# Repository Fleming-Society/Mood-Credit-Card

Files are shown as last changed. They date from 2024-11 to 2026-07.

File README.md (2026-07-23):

# Mood Credit Card

An educational electronics project from Fleming Society's 2024 Project X
programme. Participants use an ESP32-C3, a MAX30102 optical pulse sensor and
five LEDs to learn embedded programming, signal processing and PCB design.

> [!IMPORTANT]
> This is an educational demonstration, not a medical device. Heart-rate
> readings must not be used for diagnosis, monitoring or treatment.

## At a glance

| Item | Details |
| --- | --- |
| Programme | Project X 2024 |
| Topics | Arduino, ESP32-C3, sensors, I2C, signal processing and PCB design |
| Main hardware | ESP32-C3 SuperMini, MAX30102 module, five LEDs and five 220 Ω resistors |
| Firmware | Arduino sketch using the DevXplained MAX3010x Sensor Library |
| Design tools | KiCad, SolidWorks and a retained legacy DesignSpark PCB file |
| Current status | Recovered 2024 teaching pack; technical revalidation is required before another delivery |

## Project preview

| Project X workshop | Mood Credit Card model |
| --- | --- |
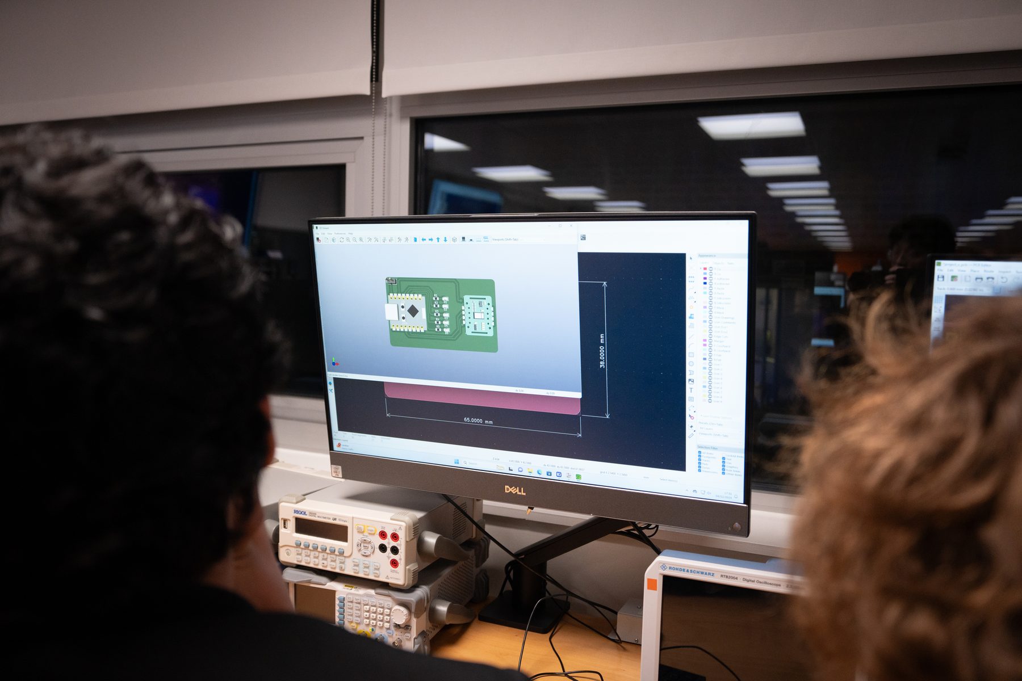
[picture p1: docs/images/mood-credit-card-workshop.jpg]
Project X participants viewing the Mood Credit Card design in KiCad
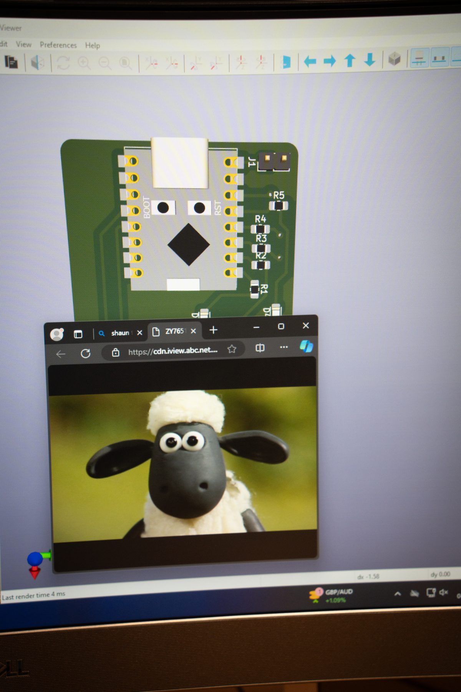
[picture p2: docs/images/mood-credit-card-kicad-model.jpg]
Mood Credit Card PCB model displayed in KiCad
|  |  |

### Circuit schematic

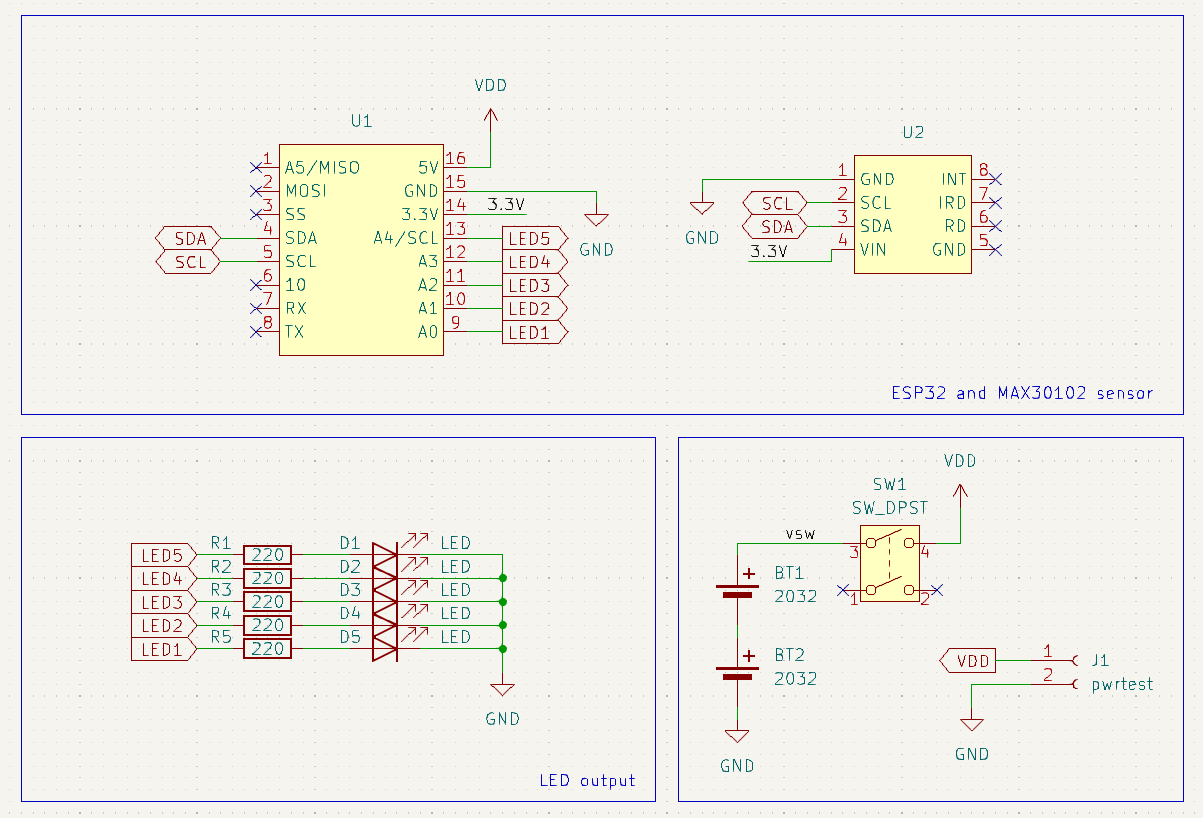
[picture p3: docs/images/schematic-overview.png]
Mood Credit Card circuit schematic


## Start here

- **Learners:** begin with the [session materials](docs/learner/README.md),
  then open the [student firmware](firmware/student/mood_credit_card/).
- **Instructors:** read the [instructor notes](docs/instructor/README.md) and
  recovered session plans before preparing a session.
- **Hardware contributors:** read the [hardware guide](hardware/README.md)
  before editing or manufacturing the PCB.

PDF handouts survive for sessions 1, 3 and 5. Session 2 now has its recovered
agenda and I2C example code. Session 5 also has editable helper slides and an
instructor plan. No separate Session 4 handout was found in the source archive.

## Repository structure

```text
.
|-- docs/             # Learner and instructor material
|-- firmware/         # Maintained code, examples and historical snapshots
|-- hardware/         # Current CAD, enclosure source and historical revisions
|-- private/          # Local-only records and raw source archives, ignored by Git
|-- third_party/      # Imported material and preserved licence texts
|-- CONTRIBUTING.md
|-- LICENSE
`-- NOTICE.md
```

This layout is intended to be reused across Fleming Society projects:
documentation in `docs/`, runnable code in `firmware/`, editable engineering
source in `hardware/`, and personal or operational records outside the public
Git history.

## Recovered 2024 material

| Material | Location | Notes |
| --- | --- | --- |
| Learner handouts, PCB guide and I2C slides | [`docs/learner/2024/`](docs/learner/2024/) | Original 2024 files; review before reuse |
| Instructor agendas and plans | [`docs/instructor/2024/`](docs/instructor/2024/) | Session 2 and Session 5 material recovered |
| I2C Arduino examples | [`firmware/examples/session-02/`](firmware/examples/session-02/) | Arduino Uno slave and ESP8266 master |
| Learner KiCad project | [`hardware/kicad/learner/`](hardware/kicad/learner/) | Complete source set recovered; not yet revalidated |
| Enclosure CAD | [`hardware/enclosure/`](hardware/enclosure/) | SolidWorks source and STL exports |
| Historical PCB revisions | [`hardware/archive/2024/`](hardware/archive/2024/) | Seven labelled development stages; caches and automatic backups omitted |

## Software setup

1. Install the Arduino IDE and ESP32 board support.
2. Install the
   [MAX3010x Sensor Library](https://github.com/devxplained/MAX3010x-Sensor-Library)
   by DevXplained.
3. Open
   `firmware/student/mood_credit_card/mood_credit_card.ino`.
4. Select the correct ESP32-C3 board and port.
5. Compile before connecting the workshop PCB.

The exact Arduino ESP32 core and library versions used in 2024 were not
recorded. Pin these versions after the firmware is revalidated.

## Validation status

| Area | Status | Required action |
| --- | --- | --- |
| Learner materials | Recovered from 2024 | Review wording, links and software screenshots |
| Student firmware | Not recently compiled | Confirm board target, library version and sampling behaviour |
| Learner KiCad project | Source set recovered | Open in the intended KiCad version; run ERC and DRC |
| Exemplar KiCad design | Source preserved | Compare with an approved fabricated board |
| Enclosure CAD | Source and STL variants recovered | Confirm assembly references, fit and preferred revision |
| Component 3D models | Withheld pending licence review | Replace with redistributable models and document provenance |
| Gerbers | Current and historical sets preserved | Identify the approved set before manufacturing |
| Bill of materials | 2024 workbook preserved | Review prices, part numbers and substitutions |
| Risk assessment | Missing | Add the current session risk assessment and supervision notes |

## Safety

- Power the board only from the documented low-voltage USB supply.
- Inspect assembled boards for shorts before connecting them to a computer.
- Do not look directly into the pulse sensor LEDs at close range.
- Follow the venue's soldering, ESD and tool-safety procedures.
- Do not collect or publish participants' health readings or attendance data.

## Contributing

See [CONTRIBUTING.md](CONTRIBUTING.md) for file-placement, privacy and review
rules.

## Licensing

Except where a file or notice says otherwise, the original teaching material,
firmware and hardware designs are available under the [MIT License](LICENSE).

Third-party material retains its original copyright and licence. See
[NOTICE.md](NOTICE.md) and the licence texts under [`third_party/`](third_party/).

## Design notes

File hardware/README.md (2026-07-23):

# Hardware

## Editable PCB sources

[`kicad/`](kicad/) contains the completed KiCad exemplar, custom symbols and
custom footprints. [`kicad/learner/`](kicad/learner/) contains the recovered
2024 learner starter project with its board, schematic and project file.

The board files use `${KIPRJMOD}`-relative references. The supplied component
STEP models are withheld from the public tree until their redistribution
rights are confirmed; see
[`kicad/3d_models/README.md`](kicad/3d_models/README.md).

## Enclosure CAD

[`enclosure/`](enclosure/) contains recovered SolidWorks source and STL
exports for the enclosure. Several back variants survive, and no preferred
release has been confirmed.

## Historical revisions

[`archive/2024/`](archive/2024/) contains seven labelled PCB development
stages recovered from the source ZIP. They are retained for traceability, not
as alternatives to the current exemplar or learner project.

## Manufacturing outputs

[`manufacturing/gerbers/`](manufacturing/gerbers/) contains the previously
selected historical Gerber and drill files. Additional revision-specific sets
are retained with their matching source under `archive/2024/`.

Do not send any set to manufacture until the schematic and PCB pass ERC, DRC
and a human design review against an approved fabricated board.

## Bill of materials

[`bom/2024/bom.xlsx`](bom/2024/bom.xlsx) is the supplied 2024 bill of
materials. Prices, stock, supplier links and part substitutions have not yet
been reviewed for a future delivery.

## Legacy source

[`legacy/`](legacy/) contains an older binary `.dip` design file. Retain it for
traceability until its application, version and relationship to the KiCad
design are documented.

## Repository hygiene

KiCad caches, user preferences and automatic backups are not public project
source. The untouched `project_x.zip` source drop is retained under ignored
`private/source-archive/` as a lossless fallback. Unverified third-party
models and libraries are held separately under `private/licensing-review/`
and are not covered by the project licence.

Before the next release:

- convert the BOM into a supplier-neutral master list with optional supplier
  columns;
- confirm board dimensions and connector pinout;
- choose and validate an enclosure revision;
- add assembly instructions and known design limitations; and
- record the KiCad version used for final ERC and DRC.

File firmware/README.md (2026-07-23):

# Firmware

The current learner starter sketch is at
[`student/mood_credit_card/`](student/mood_credit_card/).

Recovered I2C examples from Session 2 are under
[`examples/session-02/`](examples/session-02/). Historical prototype ZIP
snapshots are retained under
[`archive/2024/prototypes/`](archive/2024/prototypes/) for comparison, not as
the primary learner code.

Before the next workshop:

1. Confirm the exact ESP32-C3 board target.
2. Pin the Arduino ESP32 core and DevXplained MAX3010x library versions.
3. Compile from a fresh environment.
4. Verify that `readBPM()` is called frequently enough to sample a heartbeat;
   it should not run only once per second.
5. Resolve or document the current 3200 SPS sensor setting versus the 400 Hz
   filter sampling-frequency constant.
6. Test behaviour with no finger, poor contact and sensor disconnection.

Keep learner starter code separate from any worked solution. If solutions
must remain restricted, store them outside this public repository.

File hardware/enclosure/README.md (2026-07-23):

# Enclosure CAD

The recovered 2024 SolidWorks and STL files are grouped by development stage:

- [`2024/v3/`](2024/v3/) contains the v3 assembly, enclosure and back variants.
- [`2024/earlier-revisions/`](2024/earlier-revisions/) contains earlier
  enclosure and assembly files.

The SolidWorks assemblies may refer to component models that are not publicly
distributed because their licences are unconfirmed. Open the part files first
if an assembly reports missing references.

No preferred enclosure revision has been identified. Check dimensions,
connector access, print tolerances, board fit and sensor access before using
an STL for fabrication.

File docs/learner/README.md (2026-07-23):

# Learner materials

## Project X 2024

The recovered learner materials are in [`2024/`](2024/):

1. [Session 1 handout](2024/session-01.pdf)
2. [Session 3 handout](2024/session-03.pdf)
3. [Session 5 handout](2024/session-05.pdf)
4. [Session 5 I2C helper slides](2024/session-05-i2c-helper-slides.pptx)
5. [PCB design instructions](2024/pcb-instructions.docx)

Session 2 used an instructor agenda and I2C practical code rather than a
learner-facing handout in the recovered archive. See the
[Session 2 examples](../../firmware/examples/session-02/). No separate Session
4 learner handout was found.

Editable source files for the three PDF handouts have not yet been located.

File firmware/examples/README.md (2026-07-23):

# Firmware examples

Small, self-contained examples used by historical teaching sessions belong
here. Each Arduino sketch must stay in a directory that matches its `.ino`
filename.

The recovered Session 2 examples demonstrate I2C communication between an
ESP8266 master and an Arduino Uno slave. They have not been compiled recently.

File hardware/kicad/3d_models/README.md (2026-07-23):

# 3D model placeholders

The KiCad boards reference models for the ESP32-C3 SuperMini and MAX30102
module, but the supplied STEP files are not distributed here because their
copyright and redistribution terms have not been confirmed.

Local copies are held in the ignored `private/licensing-review/3d-models/`
directory while their provenance is investigated. Replace them with models
whose licences permit redistribution, then record their authors, sources and
licences in the root [`NOTICE.md`](../../../NOTICE.md).

The PCB and schematic sources remain usable without the 3D models. KiCad's 3D
viewer will show the corresponding components without models until suitable
replacements are added.

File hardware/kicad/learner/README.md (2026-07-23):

# Learner KiCad starter

This is the recovered 2024 learner PCB template. It contains the ESP32-C3 and
MAX30102 circuit, with the two main footprints locked, but no routed tracks or
learner-designed LED circuit.

The source set now includes:

- `project_x_pcb.kicad_pro`
- `project_x_pcb.kicad_sch`
- `project_x_pcb.kicad_pcb`
- local library tables that point to the shared custom libraries one directory
  above

The files were recovered from the full `project_x.zip` source archive. They
have not yet been opened together in the intended KiCad version or checked
with ERC and DRC, so treat them as recovered historical source rather than a
validated release.

The board's 3D model references point to `../3d_models/`, but the component
models are deliberately absent pending licence confirmation. See
[`../3d_models/README.md`](../3d_models/README.md).

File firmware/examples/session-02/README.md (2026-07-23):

# Session 2 I2C examples

| Sketch | Target | Purpose |
| --- | --- | --- |
| [`arduino_slave/arduino_slave.ino`](arduino_slave/arduino_slave.ino) | Arduino Uno | Receives text at I2C address 9 and prints it to Serial |
| [`esp8266_master/esp8266_master.ino`](esp8266_master/esp8266_master.ino) | ESP8266 | Reads Serial input and sends it to I2C address 9 |

The recovered agenda describes removing selected expressions before the
exercise so learners can fill them in. The copies here preserve the complete
reference implementations. Confirm voltage compatibility, board pins and the
installed board packages before wiring the two devices together.

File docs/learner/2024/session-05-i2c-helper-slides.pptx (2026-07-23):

## I2C exercise: Arduino_slave and Arduino_master Helper slides

## Arduino_slave: What is the task?

- This Arduino code allows Arduino to receive messages over I²C (a communication protocol) and print the received messages to the Serial Monitor.
- Specifically, the Arduino acts as a slave device with an address of 9. When data is sent to this address, the code reads the data, stores it in a buffer (a temporary storage space), and displays it on the Serial Monitor.
- Write you code following the steps and ask volunteers for help!

## Step 1: Include the Required Library

- Library: You'll need the Wire library to enable I²C communication.
- Write an #include statement at the very top of the code to include this library.
Why?
- The Wire library allows your Arduino to send and receive data over the I²C bus.

## Step 2: Define the Buffer Size

- Buffer Size: Create a constant called BUFFER_SIZE and set it to 32.
- This defines how much data (in characters) your Arduino can store when receiving messages.
Why?
- This buffer will store incoming data, and 32 is a maximum reasonable size to work with, considering Arduino's memory limitations.

## Step 3: Declare the Buffer and Index

- Buffer: Create a character array called receivedText with a size of BUFFER_SIZE.
- This will store the received message.
- Index: Create an integer variable called textIndex and set it to 0.
- This will track where the next character should be stored in the buffer.
Why?
- The buffer stores the incoming data as characters. The index keeps track of where to place each character.

## Step 4: Set Up the Arduino (Setup Function)

- Write a setup function. This function runs once when the Arduino starts. (it should be there when you create a new file)
- Start Serial Communication:
- Inside the setup, initialize the Serial Monitor with a baud rate of 9600 using Serial.begin();.
- This allows you to see messages printed to your computer.

## Step 4: Set Up the Arduino (Setup Function)

- Start I²C Communication:
- Initialize the Arduino as an I²C slave device with the address 9 using Wire.begin().
- Register the Receive Event:
- Attach a function called receiveEvent using Wire.onReceive().
- This function will automatically run whenever the Arduino receives data.
Why?
- The setup function prepares the Arduino for serial communication and I²C communication.

## Step 5: Write the Receive Event Function

- Create a function called receiveEvent that:
- Type: void (it doesn't return any value).
- Input: An integer called bytes, which represents the number of bytes available to read.
- Reset the Index:
- At the beginning of the function, set textIndex to 0 to clear the buffer for new data.

## Step 5: Write the Receive Event Function

Read Incoming Data:
- Use a loop to read each byte from the I²C buffer:
- As long as there are bytes available (Wire.available()), read one byte at a time and store it in a variable c of type char.
- Store Data in the Buffer:
- If textIndex is less than BUFFER_SIZE - 1:
- Store c in the receivedText array at the position textIndex.
- Increment textIndex by 1.
Loop to read each byte from the I²C buffer end here.

## Step 5: Write the Receive Event Function

- Add a Null-Terminator:
- After reading all the bytes, add a \0 (null-terminator) to receivedText to mark the end of the string.
Why?
- This function processes the data received over I²C and stores it as a proper string. The null-terminator is crucial to indicate the end of the text.

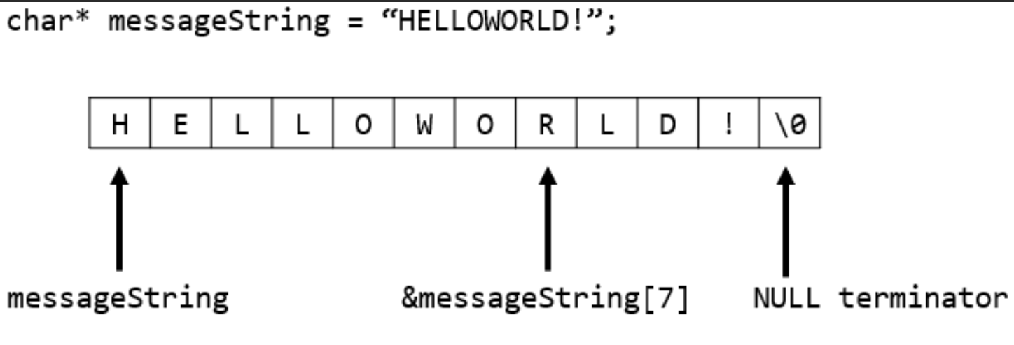
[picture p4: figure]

## Step 6: Write the Loop Function

- Create a loop function. This function runs repeatedly.(it should be there when you create a new file)
- Check for New Data:
- If textIndex is greater than 0 (meaning data has been received), print the message.
- Print the Message:
- Use Serial.println to display the message in receivedText on the Serial Monitor.

## Step 6: Write the Loop Function

- Reset the Index:
- After printing, reset textIndex to 0 to prepare for the next message.
Why?
- The loop function continuously checks if there's a new message to print. Resetting textIndex allows the buffer to be reused.

## Variable Summary for Arduino_slave

Variable | Type | Purpose
BUFFER_SIZE | #define | Maximum size of the receivedText buffer (32).
receivedText | char[] | Buffer to store the incoming message.
textIndex | int | Tracks the current position in the buffer.
c | char | Stores each character read from the I²C buffer.
bytes | int | Number of bytes available to read in the receiveEvent function.

## Arduino_master: What is the task?

- This code allows an Arduino to act as an I²C master. The master device reads input from the Serial Monitor, stores it as a string, and then sends this string to an I²C slave device (like the Arduino Uno) with the address 9.
- After sending the message, it prints a confirmation to the Serial Monitor.

## Step 1: Include the Required Library

- Library: You'll need the Wire library to enable I²C communication.
- Write an #include statement at the very top of the code to include this library.
Why?
- The Wire library allows your Arduino to send and receive data over the I²C bus.

## Step 2: Define the Buffer Size and Input Buffer

- Buffer Size: Define a constant BUFFER_SIZE with a value of 32.
- Input Buffer: Declare a character array called inputText with a size of BUFFER_SIZE.
- This array will store the text that the user inputs from the Serial Monitor.
- Why?
- The buffer allows you to temporarily store the input message before sending it over I²C.

## Step 3: Set Up the Arduino (Setup Function)

- Write a setup function. This function runs once when the Arduino starts. (it should be there when you create a new file)
- Start Serial Communication:
- Initialize the Serial Monitor with a baud rate of 9600 using Serial.begin();.
- This allows you to send and receive text via your computer.

## Step 3: Set Up the Arduino (Setup Function)

- Initialize I²C Communication:
- Call Wire.begin(); to set up the Arduino as an I²C master.
- Print a Welcome Message:
- Print a message prompting the user to type a message and press Enter.
Why?
- The setup function prepares the Arduino for communication and informs the user how to interact with the device.

## Step 4: Write the Loop Function

- Create a loop function. This function runs repeatedly. (it should be there when you create a new file)
- Check for User Input:
- Use Serial.available() to check if there is any input available in the Serial Monitor. They are available if Serial.available() is greater than 0.

## Step 4: Write the Loop Function

Read Input:
- Use the Serial.readBytesUntil() function to achieve this. This function reads characters until it encounters a newline or reaches the maximum number of characters allowed.
- Read characters from the Serial Monitor until a newline character (\n) is received, meaning the user pressed Enter or the buffer is full (up to BUFFER_SIZE - 1).
- Store the characters in the inputText buffer.
- Save the length of the input in a variable len.
- len is declared as a size_t because Serial.readBytesUntil() returns the number of characters read, which is a size value.

## Step 4: Write the Loop Function

- Add a Null-Terminator:
- Add a \0 (null-terminator) to the end of inputText to mark it as a valid string.
- Send Data via I²C:
- Use Wire.beginTransmission() to start communication with the slave device at address 9.
- Send the string stored in inputText using Wire.write();.
- End the I²C transmission with Wire.endTransmission();.

## Step 4: Write the Loop Function

- Print Confirmation:
- Print a message to the Serial Monitor showing the text that was sent. Use Serial.println();
- Prompt the user to type another message. Serial.println();
Why?
- This function continuously checks for new input and sends it to the I²C slave. Adding a null-terminator ensures the string is properly formatted.
- The if loop ends here.
- The loop function ends here.

## Variable Summary for Arduino_master

Variable | Type | Purpose
BUFFER_SIZE | #define | Maximum size of the inputText buffer (32).
inputText | char[] | Buffer to store the user’s input message.
len | size_t | Length of the input string read from the Serial Monitor.

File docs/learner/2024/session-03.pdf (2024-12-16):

Project X Session 3 Handout

ARTICLE

## Project X Session 3 - PCB Design Using KiCAD

Junzhe Chen, Oli Sharratt, and Yuxuan Han

Introduction
In the third Project X session, you will be introduced how to design your first printed circuit board (PCB)

using KiCAD.

Contents

1 General PCB Design Workflow Introduction | 3
2 KiCAD Template & Tasks | 4
3 Start With KiCAD | 4
4 Schematic Design | 6
5 PCB Design | 11

2 | Project X Session 3 Handout
6 Design Rule Check | 16
7 Congratulations | 16
8 Appendix I: ESP32C3 Super Mini | 17
9 Appendix II: MAX30102 | 17
10 Appendix III: KiCAD Shortcuts | 18

Project X Session 3 Handout 3

### 1. General PCB Design Workflow Introduction

### 1.1 Overview

When designing a PCB, the process typically involves the following steps:

- Create a schematic: Draw the circuit diagram showing the components and their connections.
- Assign footprints: Map each component to its physical interface on the PCB.
- Design the PCB layout: Arrange footprints, draw traces, and prepare the board for fabrication.
- Fabricate the PCB: Manufacture the PCB based on the design file.
- Populate and solder components: Place and solder components onto the fabricated PCB.
- Test the PCB: Verify the board’s functionality and ensure it works as intended.

### 1.2 Detailed Explanation

The first step is creating a schematic. This is a circuit diagram that represents the electronic components using standardised symbols. An example of a PCB schematic looks like Figure 1.

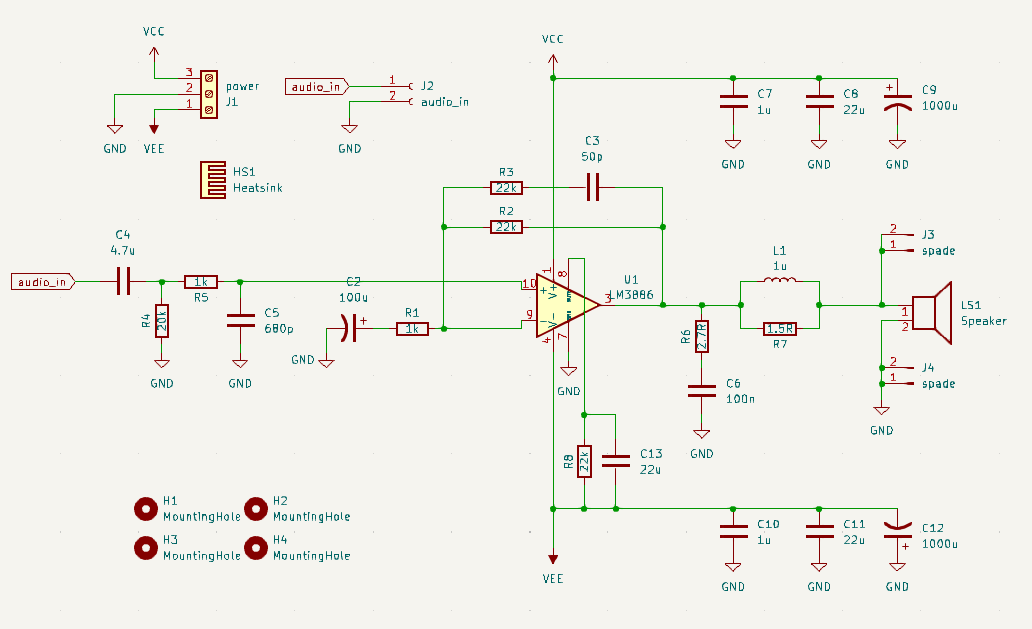
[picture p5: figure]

Figure 1. Example of a PCB Schematic

After completing the schematic, the next step is assigning footprints to the components. A footprint represents the physical dimensions of the component, along with the locations and dimensions of its connectors. This is used in the PCB layout so it can be position correctly without interfering with other components on the PCB.
Once the schematic is complete and the footprints are assigned, the next step is to design the PCB layout. This involves drawing the physical board, arranging the footprints, and adding traces to connect the components electrically. In the PCB design file shown in Figure 2a, the footprints correspond to the schematic symbols, and the traces connect them. Figure 2b illustrates a 3D rendered image of the PCB design.

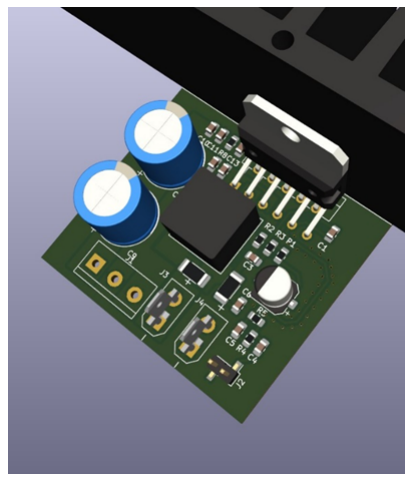
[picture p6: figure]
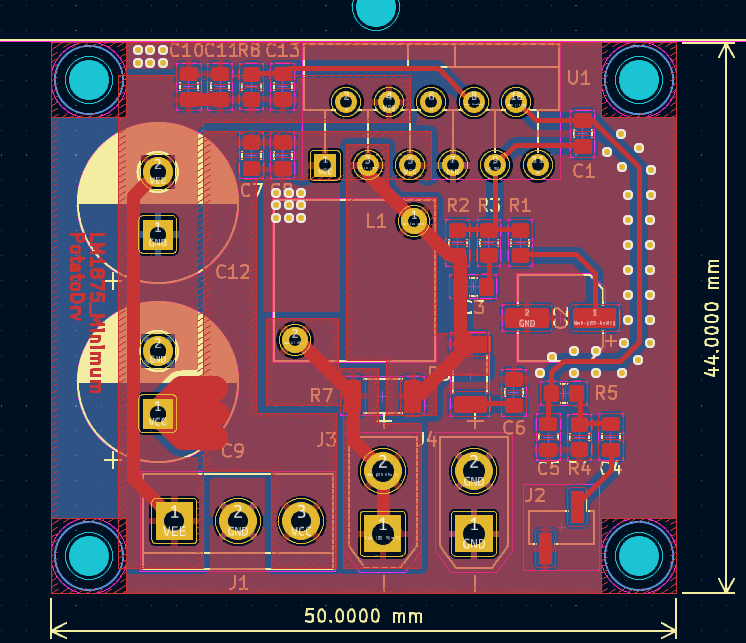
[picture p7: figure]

(a) PCB Layout Example | (b) 3D Rendered PCB

Figure 2. PCB Layout

For a typical two-layer PCB design in KiCAD, the top layer is shown in red, while the bottom layer is in blue. A significant portion of the design is covered with copper, which connects to the ground (GND) of the circuit. This approach minimizes return path impedance, a common practice in PCB design.
For Project X, after completing the PCB design, it will be sent to the UCL PCB lab for fabrication. Producing a double-layer PCB usually takes one day. Once the PCB is fabricated, the components are populated and soldered onto the board. Finally, the testing phase begins to ensure the PCB functions as intended.

### 2. KiCAD Template & Tasks

To begin with, we have drawn part of the important parts of the mood card project: the microcontroller and the sensor. These are placed in the schematics and the layout. The edges of the board have also been added to constrain the dimensions as we will panellise (put in to a grid) all boards in to sheets for fabrication. Your tasks will be the following:

- Connect the traces between the microcontroller and the sensor.
- Design and layout your own LED circuits.
- [Advanced] Try to make the footprints of the microcontroller and sensor.

### 3. Start With KiCAD

### 3.1 Open KiCAD Project

Firstly, open the KiCAD project file via File > Open Project. The KiCAD project file contains both the schematic, and the PCB layout files inside the file directory and it will be displayed in the Project Files section.

### 3.2 Schematics and PCB File

The screenshot in Figure 3 displays what will be seen when opening the project file. The most important files are the schematics and the PCB layout files, which ends with ‘_sch’ and ‘_pcb’ respectively.

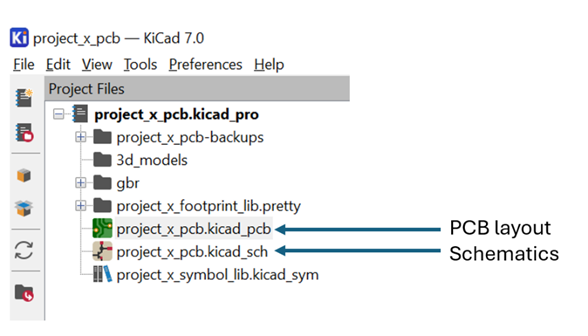
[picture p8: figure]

Figure 3. PCB Layout and PCB Schematic Files in Project View

Try to open the schematics and PCB files by double clicking each item - you should be able to see the following shown in Figure 4. Where Figure 4a shows the schematic template, and Figure 4b shows the PCB in the design template. The microcontroller (U1) and the sensor (U2) has been placed. However, the traces have not been placed yet.

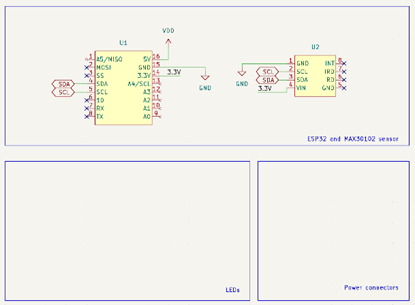
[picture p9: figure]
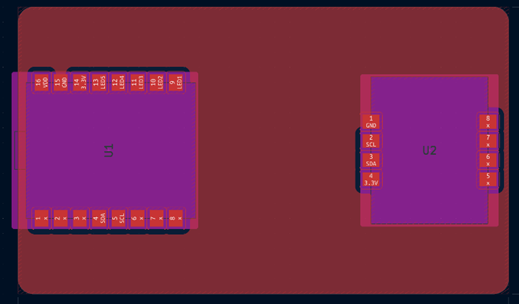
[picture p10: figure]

(a) PCB Schematic Template | (b) PCB Layout Template

Figure 4. The templates you will use

You will need to route the traces between the microcontroller and the sensor, design your LED circuits in schematics and lay it out onto the PCB, as well as adding a battery connector to the PCB to supply power to the microcontroller and the sensor.

### 4. Schematic Design

### 4.1 Toolbar

On the right-hand side of the schematic editor, there is a tool bar. You will use the toolbar to edit, add the components and wiring the connections most of the time. The commonly used tools with its shortcut keys are shown in the screenshot in Figure 5.

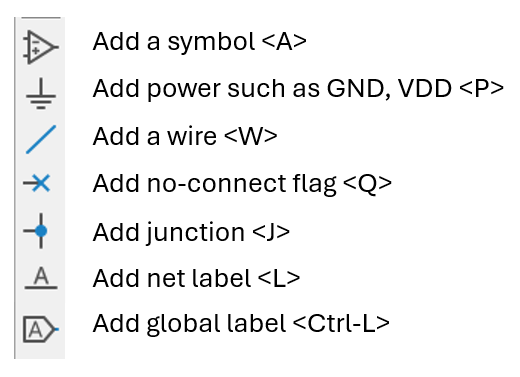
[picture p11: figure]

Figure 5. Commonly used tools in the toolbar

### 4.2 Add Components

To add a component, click the Add a symbol icon or press <A> in the keyboard. The following window in Figure 6 will be opened. The components can be found by using the search bar on the top. In this example, we are searching a LED in the symbol library and the symbol is shown on the top right. After selecting the symbol you want, press OK and then the symbol can be placed on the schematic.

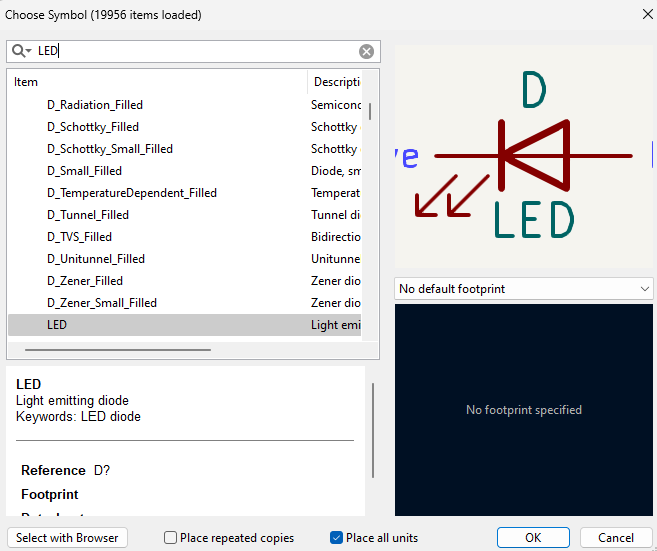
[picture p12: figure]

Figure 6. Add an LED to the schematic template.

Task: Place one LED and one resistor in the schematic’s LED region.

### 4.3 Connecting Components with Wires

After placing down the components, we can start connecting them. To connect components together, we can move the cursor close to the unconnected pin (marked with small circle), and a wire will be generated for us to connect. A better method is to use the Add a wire button in the toolbar (or use the shortcut <W>) to connect the symbol together.

Figure 7. Connect components with wire.

In Figure 7, may notice that the value of resistor is R but not the exact value we want (220). To change this, double click on the R, then the value of the resistor can be modified in the following window shown in Figure 8:

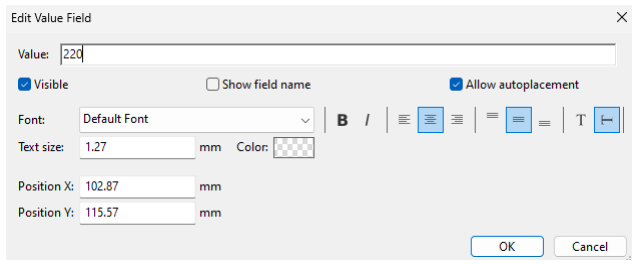
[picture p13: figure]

Figure 8. Edit resistor value.

### 4.4 Good Practice: Use "Nets" to Connect Components

4.4.1 A Negative Example
As the number of wires in a schematic increases, the design can become difficult to read and manage. A negative example is shown in Figure 9, where only wire connections are used instead of implementing

net connections.
Using net connections can greatly simplify the organization of a schematic. Nets not only reduce the mess of wires but also improve readability by assigning names to connections. These net names are carried into the PCB layout stage, which can save time during the Design Rule Check (DRC).

For example, knowing the name of a problematic net makes it easier to identify and fix connection

errors.

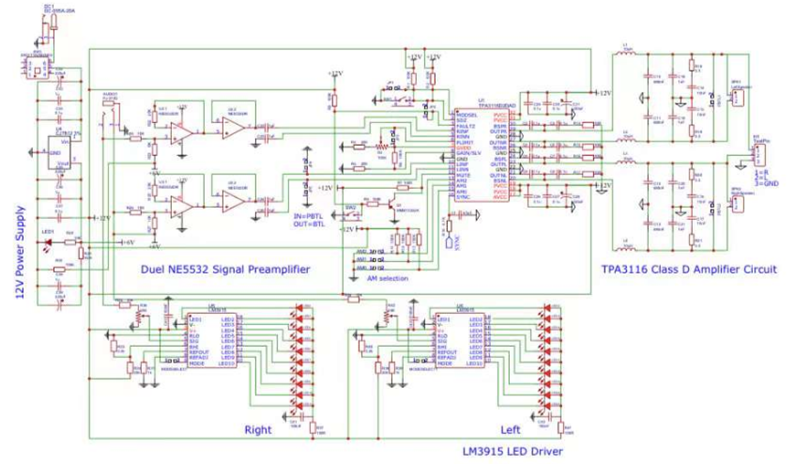
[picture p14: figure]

Figure 9. Negative example of not using net connections.

Note from editor: Don’t be afraid, the schematic you are going to design will be much simpler than this.

4.4.2 Two Net Types in KiCAD
There are two main types of nets in KiCAD:
1. Net Label (shortcut: <L>):
A net label assigns a name to a specific net, effectively "labelling" it. If two nets share the same label, they are automatically connected. This can be verified using the highlight tool (Figure 10).

Figure 10. Net Labels

Disadvantages: While net labels are useful for naming connections, they do not indicate the characteristics of the net, such as whether it is an input or output. Additionally, net labels work only within a single schematic sheet and are not carried over to other sheets in multi-sheet designs.
2. Global Label (shortcut: <Ctrl-L>):
A global label not only connects nets with the same label but also specifies their characteristics, such as input, output, or power. (See Figure. 11)

Advantages Compared to Net Label: Unlike net labels, global labels are accessible across different schematic sheets, making them suitable for multi-sheet designs.

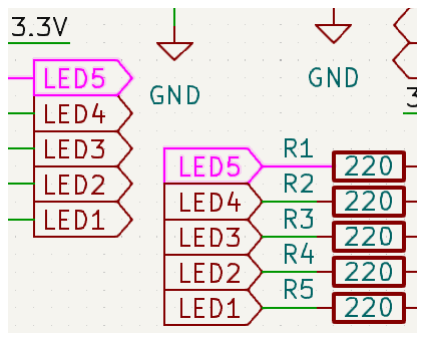
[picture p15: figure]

Figure 11. Global Labels

Task: Please try to connect the LEDs to the microcontroller using global labels.

### 4.5 Assign Footprints

At this stage, the schematic design should be complete. This means that all component symbols have been correctly connected using net labels and verified by the volunteers. The next step is to assign the corresponding footprints to the symbols.
To assign footprints, use the top menu bar and navigate to Tools > Assign Footprints... (See Figure 12a) or click the following icon on the top toolbar (See Figure 12b).
Once the footprint assignment tool is opened, the wizard will appear as shown in Figure 13. The footprint assignment tool is divided into three columns:
- Left column: Displays the footprint library, which contains all available footprints.
- Middle column: Lists the symbols in the schematic. Symbols without assigned footprints are highlighted in yellow for easy identification.
- Right column: Shows the filtered footprints, based on the criteria entered in the footprint filter.

To find a specific footprint:

1. Use the Footprint Filters in the top bar of the wizard.
2. Type the name of the desired footprint into the search bar.
3. The filtered footprints will appear in the right column.

Figure 14 shows the correct footprints for the LED after applying the footprint filter with correct keywords. Once the correct footprint is identified, double-click it to assign it to the corresponding symbol. Repeat this process for all symbols in the schematic. (Remember that different components have different footprints!)

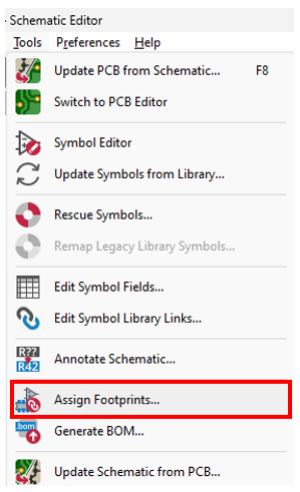
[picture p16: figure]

(a) Assign Footprint via Menu | (b) Assign Footprint via Top Toolbar

Figure 12. Two ways to enter the footprint assignment wizard.

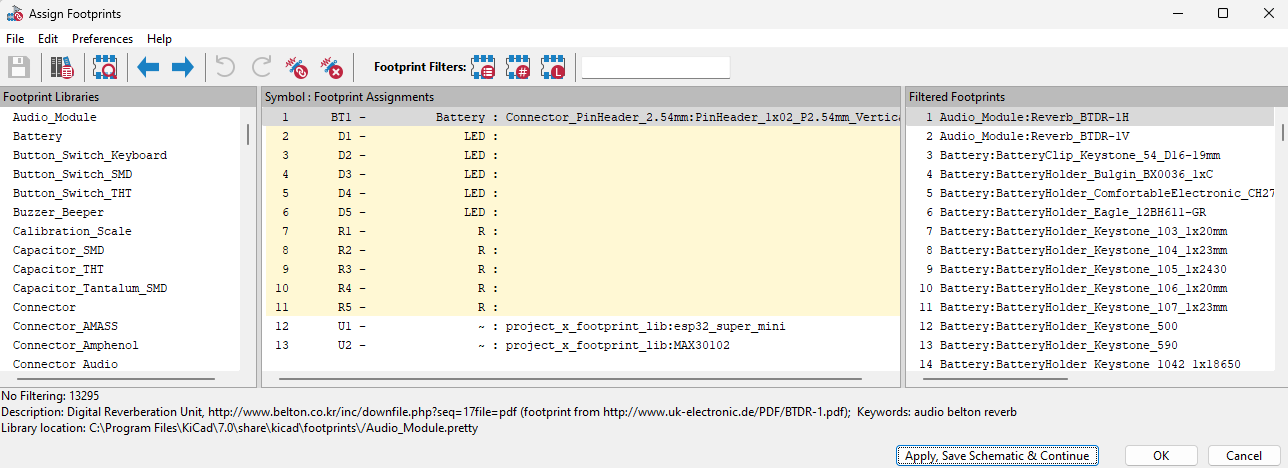
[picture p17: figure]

Figure 13. Footprint Assignment Wizard

Table 1. Footprints for your first PCB.

Component Types | Search keyword | Footprints
Resistors | R 0805 | Resistor_SMD:R_0805_2012Metric_Pad1.20x1.40mm_HandSolder
LEDs | LED 0805 | LED_SMD:LED_0805_2012Metric_Pad1.15x1.40mm_HandSolder
Batteries | header 1x02 2.54 vertical | Connector_PinHeader_2.54mm:PinHeader_1x02_P2.54mm_Vertical

The footprints that you will use are listed in Table 1.

Figure 14. Correct footprints after filtering

Task: Assign the footprints to the symbol. After that, ask one volunteer to check.

### 4.6 Final Check: Schematic Design

Please ask one of the volunteers to check if your schematics is correct. If so, you could move onto the PCB design in the next section.

### 5. PCB Design

Congratulations on completing your schematic design and having it reviewed by the volunteers! Now, it’s time to move on to the PCB design phase.

### 5.1 Importing and Placing Components

When you want to start doing PCB layout:

1. First, open the ‘_pcb’ file.
2. Second, navigate to Tools > Update PCB from schematics on the menu bar, or press <F8> on your keyboard.

A window like the one shown in Figure 15 will pop up. If there are no errors or warnings, click Update PCB. Once updated, the component footprints from your schematic will appear at your mouse cursor, as shown in the Figure 16 below:
In the PCB layout, you will notice thin blue lines connecting different pins or components—these are called ratlines. Ratlines represent the physical connections between the pins based on the schematic. When choosing where to place the components, it is best to look at the ratlines so that the ratline has the least crossing. As ratline indicates the physical connections between the pins, making them to have least crossing will make the trace routing much easier.

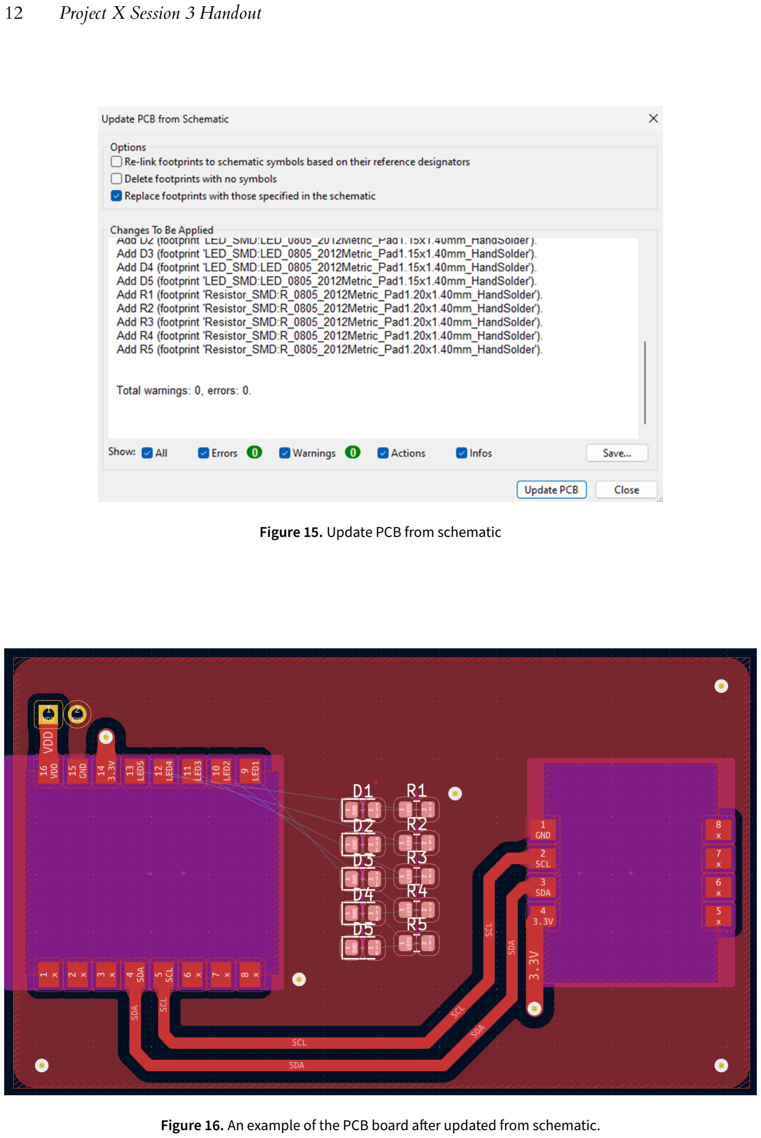
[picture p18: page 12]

Figure 15. Update PCB from schematic

Figure 16. An example of the PCB board after updated from schematic.

### 5.2 Setting Up Design Rules (IMPORTANT)

5.2.1 Open Board Setup
After placing the components to the appropriate position, the routing can begin. But before start routing, it is important to set appropriate trace width, clearance and other parameters so that the board can be manufactured from the UCL lab. To do that, click board setup, which is on the top left corner of the PCB editor (See Figure 17 below).

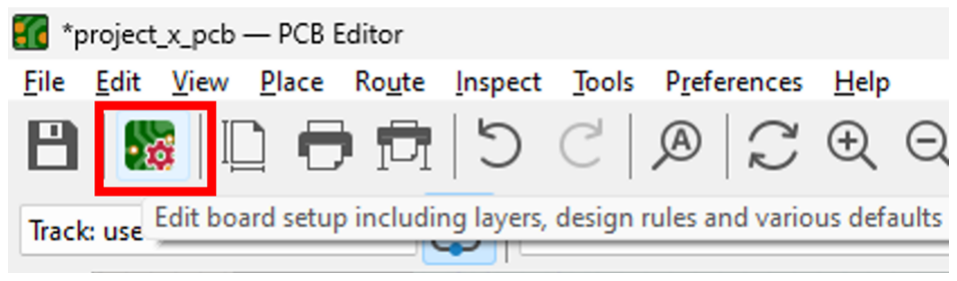
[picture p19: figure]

Figure 17. Find and click the "board setup" icon

5.2.2 Set Up Constrains
After opening the board setup, go to the constraints page and fill in the following parameters. The Copper section is the most important section for reaching the UCL lab manufacture. Please fill in the constrains exactly the same as those shown in Figure 18 below, so that the requirements can be met for PCB manufacture.

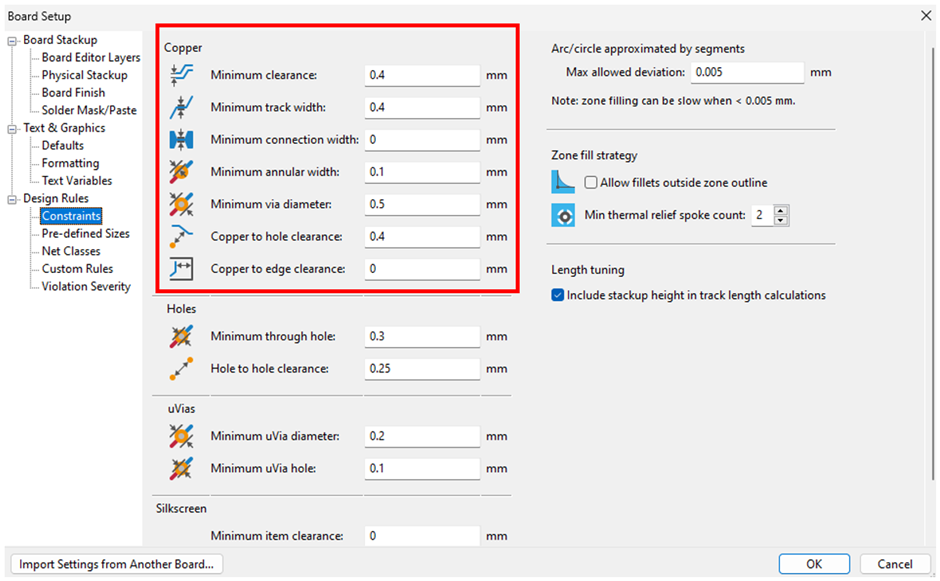
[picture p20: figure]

Figure 18. Design Constraints.

5.2.3 Set Up Pre-defined Sizes

The Pre-defined Sizes settings define the properties of tracks, vias, etc. that you will use for routing. Firstly, we need to setup the track width. Go to Pre-defined Sizes (which is just under Constraints, and the Track property should be shown on the left column (see Figure 19). As indicated by the constraints, the track cannot be thinner than 0.4 mm. So, a track width larger than 0.4 mm should be added. You can edit multiple pre-defined sizes for the tracks, depending on the type of track you are routing. For example, when routing power tracks, like VDD and 3V3, since they draw more current than signal tracks, they are usually thicker.

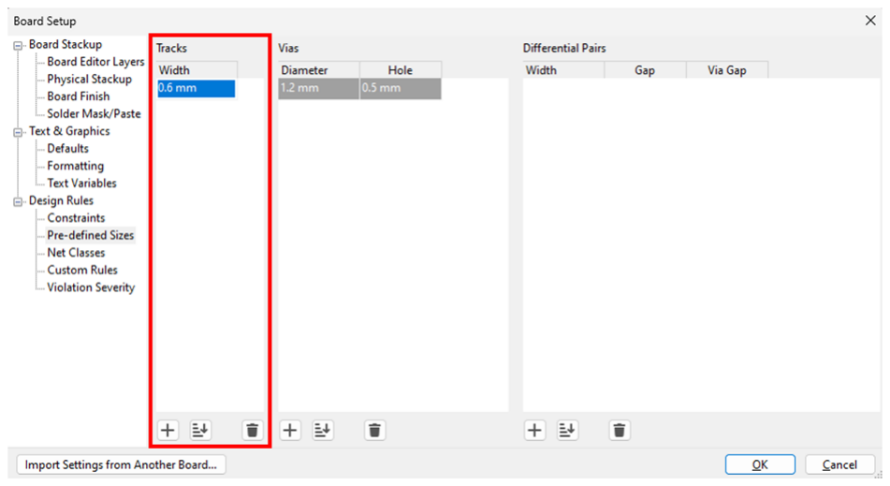
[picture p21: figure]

Figure 19. Pre-defined Sizes

For vias (in the next column), UCL uses specific size vias. The via size should be set as same as the given example in Figure 19 (Diameter = 1.2 mm, Hole = 0.5 mm).

Task: Set the constraints and pre-defined sizes and ask one of the volunteers to check.

### 5.3 Track Routing

After setting the board setup, it is the time to route the tracks.

To route the track in KiCAD, firstly, place the cursor on the pad we want to route, and then press the routing key <X> to enter the routing mode. The pads that need to be connected will be highlighted. (See Figure 20)

A copper pour is already added for this board, which connects all the ground connection, so you do not need to connect the GNDs. Remember to update the copper pour when you finished routing the tracks. This can be achieved by pressing <B>.

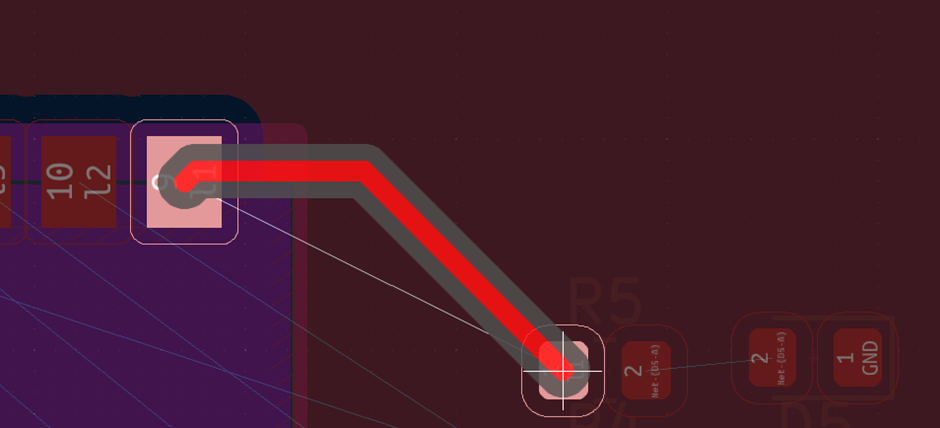
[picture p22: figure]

Figure 20. Route a track

### 5.4 Using Vias to Switch Layers

Sometimes, it is difficult to route certain tracks that goes across other tracks. In this case, it is good to switch the layer to “bridge” the track over (or under) it.
To connect the top and bottom together, a via is required. Via is a hole that is made right between the bridging tracks, and it connects the top and bottom together by plating the copper across the hole. When placing the track to the desired position, press <V>, then a via will be generated on the cursor. Move the via to the desired place, then click the left mouse button, the via will then be placed. (See Figure 21a)

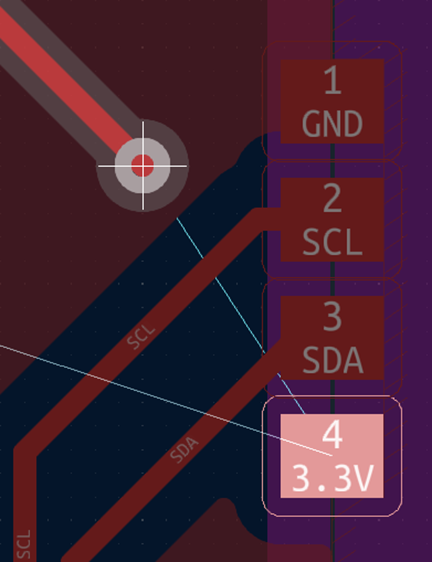
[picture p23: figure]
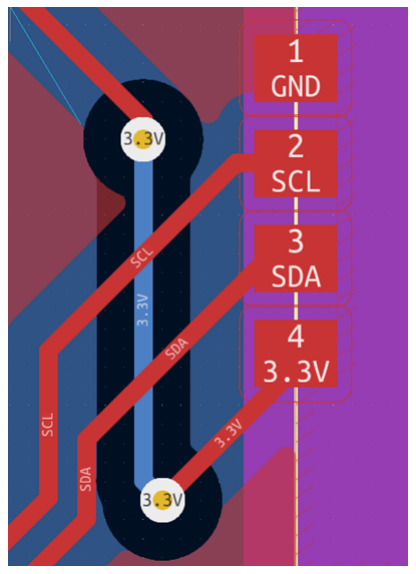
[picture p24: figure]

(a) Placing a via. | (b) A trace with vias.

Figure 21. Using vias during routing.

After placing the via, the KiCAD will automatically switch the track to the bottom layer, where the background is showing in blue. Then route the bottom track across the “bridge”, press <V> again, then the track will be completed as shown in Figure 21b.

### 6. Design Rule Check

After the routing has been completed, it is necessary to perform design rule check (DRC) before sending the design file to be manufactured. The design rule check can be found in Inspect/Design Rule Checker in the menu bar shown in Figure. 22a below:

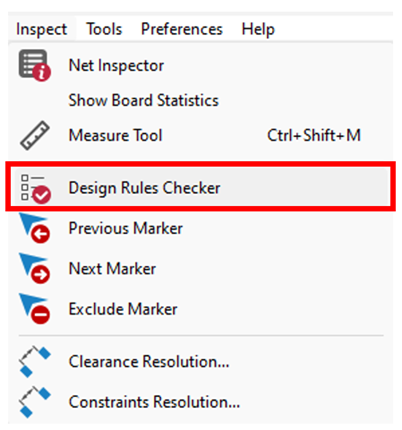
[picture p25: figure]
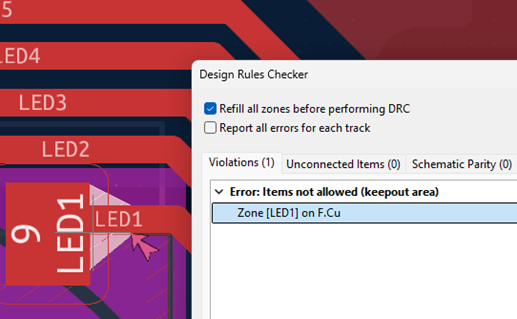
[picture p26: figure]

(a) Design Rules Checker in the menu. | (b) An error in the DRC report.

Figure 22. Performing design rule check.

If the DRC reports an error (See Figure. 22b for example), a quick way to locate the error is by double-click the error. Usually, the error will be highlighted as shown above in the right screenshot. It is important to keep the design error-free, so that it maximizes the chance of getting a working board after the board have been fabricated out.

### 7. Congratulations

Congratulations to make it till this far! The PCB should be ready and please ask one of the volunteers to check if your board is correct and ready for fabrication!

### 8. Appendix I: ESP32C3 Super Mini

(a) Pinout of the ESP32C3 Super Mini Board

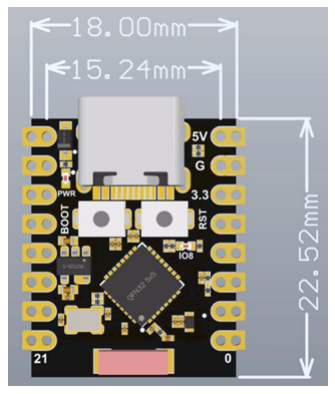
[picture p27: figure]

(b) Dimensions of the ESP32C3 Super Mini Board

Figure 23. ESP32C3 Super Mini Board pinout and dimensions.

### 9. Appendix II: MAX30102


(a) Pinout of MAX30102 | (b) Dimensions of MAX30102

Figure 24. MAX30102 pinout and dimensions.

### 10. Appendix III: KiCAD Shortcuts

Schematic Editor
Shortcut | Action
M | Move a component
R | Rotate a component
X | Flip a component
E | Edit a component
G | Drag a component
Del | Delete a component
W | Place a wire
P | Place a power symbol
L | Place a label
CTRL + L | Place a global label
F1/F2 | Zoom in/out

General Shortcuts
Shortcut | Action
Left click/drag | Select item(s)
Right click drag | Navigate canvas
Middle click drag | Navigate canvas
Scroll in/out | Zoom in/out
Ctrl + S | Save the document
Ctrl + Z | Undo
Ctrl + Y | Redo
Ctrl + C | Copy
Ctrl + V | Paste
Ctrl + X | Cut

PCB Editor
Shortcut | Action
M | Move an item
D | Drag an item
R | Rotate an item
E | Edit an item
Del | Delete an item
X | Place a track
V | Add a via
B | Rebuild copper zones
H | Cycle layer display options
Ctrl + F | Find a component
Alt + 3 | 3D viewer

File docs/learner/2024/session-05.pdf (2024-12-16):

Project X Session 5

HANDOUT

## Project X Session 5 - Programming the Mood Card

Oli Sharratt, Junzhe Chen, and Yuxuan Han

Introduction
In the fifth (and final) Project X session, you will be introduced how to program the ESP32-C3 SuperMini on your Mood Credit Card to display a representation of your current heart rate.

Contents

1 Programming | 2
2 Troubleshooting | 4
3 Appendix I: ESP32C3 Super Mini | 5
4 Appendix II: MAX30102 | 5

2 Project X Session 5

### 1. Programming

### 1.1 Setting up the File

To begin with, we need to setup the file for all components to operate as expected. The MAX3010x library need to be installed to make everything up and running. To do this, go to Tools/Manage Libraries and search for MAX3010x to install the correct library. You should obtain something shown in Fig. 1


Figure 1. Install the library for the sensor

Each LED is connected to a different pin on the microcontroller, which have different names that can be used to address them - a digital pin can be referred to by its number (e.g. 13 for digital pin 13), and an analogue pin can be referred to by A followed by its number (e.g. A2 for analogue pin A2). Looking at the PCB schematic, we are using pins A0 to A4, as shown in Fig. 2.


Figure 2. PCB Schematic of Generic Board Showing Microcontroller Connections to LEDs.

Task: Define the pins of each LED using the #define command to variable names (e.g. LED1, LED2, etc.), then try to light them up.
Depending on how you choose to address the LEDs, the pinMode command may be required or not. See section 1.3 for more information.

Project X Session 5 3

### 1.2 Getting a value of BPM

To receive an integer value of the beats per minute (BPM), call the function readBPM(). When this is assigned to a variable (in the scope of main()), this value will update every time the loop runs. Then you can use it for LEDs representation in whatever way you choose.

Task: Declare a temporary variable to store the integer value of BPM above the setup() section. In loop(), set the output of readBPM() to this variable.


Figure 3. Screenshot of Serial Monitor after obtaining the sensor reading

### 1.3 Addressing LEDs

Outputting to an LED can be done in a few different ways and produce different results. We have two commands we can use: digitalWrite() (https://reference.arduino.cc/reference/en/language/functions/digital-io/digitalwrite/) or analogWrite(). (https://reference.arduino.cc/reference/en/language/functions/analog-io/analogwrite/) A digital pin will use a digital signal (logic 0 (LOW) or logic 1 (HIGH)), and will be a fixed brightness. Using the digitalWrite() command will take two values; the LED pin being addressed (via its corresponding variable name), and the logic level desired - e.g. digitalWrite(LED1, HIGH). However, as stated earlier, an additional command is required pinMode() (https://reference.arduino.cc/reference/en/language/functions/digital-io/pinmode/) needs to be defined for each pin. This command belongs in the setup() function and takes two arguments - the LED being addressed, and the mode it should operate in (INPUT, INPUT_PULLUP, or OUTPUT). In this case, LEDS are output devices, so all LED pins should be set to OUTPUT, e.g. pinMode(LED1, OUTPUT).
An analogue pin will output a Pulse Width Modulated (PWM) (https://docs.arduino.cc/learn/microcontrollers/analog-output/) signal which is a square wave of varying on/off time and can provide a range of brightness values according to the ratio of time on to time off. Once again, this will take two values: the LED pin being addressed and the output level. The output level, is a value between 0-255, simulating 0V to 3.3V. This should correlate with the brightness of the LED, and analogWrite(LED1, 128) should be approximately half brightness.

4 Project X Session 5

### 2. Troubleshooting

### 2.1 Boot Mode & Reset Button

If you get an error of ‘Exit status 2’ and the code does not upload, unplug the board, then plug it back in whilst holding the BOOT button on the ESP32-C3. See Fig. 4a for more details. This should fix the uploading issue, but the board still may not be working correctly - try pressing the RST (or Reset) button, to see if that helps.

### 2.2 I’m not getting a reading from the sensor!

This is a common issue and can be related to a number of things. First, check that the PCB is powered, the microcontroller has LEDs on, and the heart rate sensor is glowing red. The second issue may be related to the positioning of the finger on the sensor. When using it, hold still, and apply consistent pressure. However, don’t press too hard, as no reading will be given, but also don’t press to lightly, as this will give an erroneous reading.

Congratulations
Congratulations for making it to the end! You should now have a fully functional heart-rate sensing device.

Project X Session 5 5

### 3. Appendix I: ESP32C3 Super Mini


(a) Pinout of the ESP32C3 Super Mini Board


(b) Dimensions of the ESP32C3 Super Mini Board

Figure 4. ESP32C3 Super Mini Board pinout and dimensions.

### 4. Appendix II: MAX30102


(a) Pinout of MAX30102 | (b) Dimensions of MAX30102

Figure 5. MAX30102 pinout and dimensions.

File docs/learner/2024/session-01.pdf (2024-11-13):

UCL Fleming Society - Project X Session 1

ARTICLE

## Project X Session 1 - Introduction to Arduino IDE and ESP8266

Yuxuan Han, Junzhe Chen, and Oli Sharratt

Introduction
In the first Project X session, you will recall basic electronic theorem, and learn how to use Arduino IDE to program the ESP8266 microcontroller board. Try to follow the instructions in this document and first your first two simple programs: Blink and Hello World.

### 1. Configure Arduino IDE for ESP8266 1.1 Library, board and port

To make sure the Arduino IDE can program the ESP8266 without any problem, the following procedures should be done:

- Download the ESP8266 library
- Select the correct ESP8266 board to program
- Select the correct port to communicate between the ESP and the Arduino IDE Follow this link to learn how to configure the Arduino IDE for the ESP8266: https://randomnerdtutorials.com/how-to-install-esp8266-board-arduino-ide/

### 1.2 Pin-out of the ESP8266

Figure 1 below is the pin-out of the ESP8266 board. It defines the functions of all the pins on the board. It is not that important for today’s session, but you may need this pinout diagram in the future, for example, finding the I2C pins.

### 2. The Blinky Program

For the blink program, you will program your ESP8266 board to blink an external LED.

### 2.1 Build the External Circuit

Please build the circuit for the Blinky program according to Figure 2. Pay attention to the legs of the LED. The longer leg is the anode (+), where the current flows in, and the shorter leg is the cathode (-), where the current flows out.
To connect the LED to the microcontroller shown in Figure 2, we need to use a breadboard. This is an external board where you can connect through-hole components (those components with pins) together quickly without needing to solder. It is very often used when prototyping such as making a blinky program and testing a sensor.
According to the circuit connection in Figure 3. If we want to illuminate the LED, the pin D5 should be turned to logic high (i.e. supplying 3.3 V). Similarly, if we want to turn off the LED, the pin D5 should be turned to logic low (i.e. supplying 0 V). Thus, if we alter the D5 pin output between logic low and logic high, the LED will start to blink.

2 UCL Fleming Society - Project X Session 1


Figure 1. Pin-out of the ESP8266


Figure 2. Circuit connection for Blinky


Figure 3. LED connection for blink program

UCL Fleming Society - Project X Session 1 3

Table 1. Pins used for Blinky

Pin Used | Connected to | Purpose
D5 | LED Anode | Supply power to and control the LED
GND | LED Cathode | Ground

### 2.2 Program the C Code

The C code of the Blinky program has been provided in Figure 4. You can try to create a new file in Arduino IDE, and type it in. Let’s go through all the lines of this blinky program together and try to understand their meaning.


Figure 4. C code for blinky

When you created a new file in Arduino IDE, you may already noticed that there are already some pieces of code written inside: void setup() and void loop(). They are the most important two functions in Arduino and each of them follows a pair of curly braces ‘{ }’. Each pair of curly braces represents a section of code, which is the content of the function. For the setup function, the code inside will only be executed once when the microcontroller powers up or after being reset manually. For the loop function, the code inside will be executed in a cyclic behaviour, line by line, after the setup function finished - that’s also why it is called loop.
Line 1 of the code is a macro definition. The effect of this line of code is to tell the computer, if you see the word "LED" again below this line, replace them with D5, which is the pin number that we connect the LED to. Using macro definition is a good practise of coding. For example, if you want to change the LED pin number at a later point, you only need to edit the macro definition line once and no need to search and change all of the pin numbers inside a large amount of code. Line 3 - 6 is the setup function. One important thing we need to do is to configure the D5 pin as an output device. This is done in line 5.
Line 10 - 14 is the loop function. In the loop, we want the D5 pin to continuously toggle high and low, to blink our LED on and off. In line 10, we configure the LED D5 pin to logic high (3.3 V), and in line 11, we let the microcontroller to wait for 1000 milliseconds (1 second) by using delay(1000). Then, in line 12 we configure the LED pin to logic low (0 V), and in line 13 we wait for another 1000 ms. The loop function then comes to the end. However, since it is a "loop", the microcontroller will jump back to line 10 and re-execute the code in this section.

4 UCL Fleming Society - Project X Session 1

### 2.3 Compile and Flash the Code

After you finished typing in the code in Figure 4 and correctly configured the Arduino IDE by following the instructions in Section 1.1, you can upload your code to the ESP8266. To compile and flash the code onto the microcontroller and see the code running, you can press the upload icon on the top-left corner of the Arduino IDE, or simply use <Ctrl+U>. The code will automatically be compiled and uploaded onto your board.
If you are unable to upload the code, or see any error message, or your LED light does not blink, please call the volunteer near you and we can offer you some help.

### 2.4 Serial Communication

The microcontroller and the computer can communication with each other. One of the popular communication protocols between the microcontroller and the Arduino IDE is Serial communication.
The first step is to set up the microcontroller to begin the serial communication. The command Serial.begin(baud_rate) in the setup loop represents the configuration of the serial communication. The baud rate indicates how fast the microcontroller will make communication with the computer per second, usually 115200 is a common baud rate to use, as seen in line 3 of the example code.


Figure 5. Codes and serial outputs of example serial communication

When the serial communication is enabled, we can use the Serial.print or Serial.println to print out text or variable values through serial and view them in the serial monitor. To open serial monitor, go to the top bar and click Tools/Open Serial Monitor. Alternatively, click the magnifying glass icon on the right hand side of the Arduino IDE or press <Ctrl+Shift+M>.
It is important to set the baud rate of the serial monitor to be the same as the initiated baud rate. Sometimes, it is a good practice to perform a sanity check in the setup function. Line 4 will be printed out when the serial connection initiated. If the baud rate is set to be faulty, the information will not be corrected displayed, which can be a hint during the debugging process.

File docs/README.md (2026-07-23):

# Documentation

- [`learner/`](learner/) contains public instructions, handouts and slides.
- [`instructor/`](instructor/) contains recovered agendas, session plans,
  preparation guidance, safeguarding notes and risk information.
- [`images/`](images/) contains project screenshots used by the root README.

Keep editable source files alongside exported PDFs whenever possible. Use a
year subfolder only for genuinely historical deliveries; maintain current
instructions at a stable path.

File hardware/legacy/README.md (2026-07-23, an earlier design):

# Legacy hardware source

Files here are retained for traceability but are not the primary editable
design.

`project_x_pcb_exemplar.dip` is a binary PCB design file whose original
application/version and relationship to the KiCad source still need to be
confirmed.

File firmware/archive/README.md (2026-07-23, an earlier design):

# Firmware archive

This directory preserves historical code snapshots for traceability. It is not
the primary location for maintained or learner-facing firmware.

The 2024 prototype ZIPs contain two different revisions of the same Arduino
sketch. The `2024-12-07/project_x_prototype/` directory preserves a later
snapshot in the folder structure required by the Arduino IDE.
Keep these revisions until their differences have been reviewed and any useful
history has been converted into normal Git commits or documented releases.

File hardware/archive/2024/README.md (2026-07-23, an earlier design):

# 2024 hardware archive

These directories preserve meaningful Project X PCB development stages from
the original source drop. Each revision is self-contained where the recovered
files permit it.

| Directory | Description |
| --- | --- |
| `early-mood-creditcard-v1.0/` | Early schematic and almost-empty PCB placeholder |
| `session-1-v1.1/` | First substantial Session 1 KiCad design and Gerbers |
| `session-1-v2/` | Later Session 1 design, Gerbers and legacy DipTrace source |
| `project-x-v3-portrait/` | Portrait 65 mm by 38 mm design revision |
| `project-x-v3.1/` | Later Project X design with Gerbers and DipTrace source |
| `learner-old/` | Earlier learner project, manufacturing output and laptop-specific board variant |
| `session-1-incomplete/` | Isolated project file retained because its board and schematic were absent |

Automatic backups, caches, lock files, user preferences and autosaves were
not copied into the public archive. Repeated board STEP exports and component
3D models were also excluded because their embedded or source-model licensing
has not been confirmed. The untouched source ZIP remains under ignored
`private/source-archive/`.

These revisions have not been revalidated. Do not manufacture from them or
present them as current teaching material.

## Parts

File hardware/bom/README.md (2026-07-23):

# Bills of materials

Store one reviewed bill of materials per hardware revision or historical
delivery.

The archived 2024 workbook is at [`2024/bom.xlsx`](2024/bom.xlsx). Before
reuse, check:

- quantity per kit and total quantity;
- manufacturer part number;
- electrical and mechanical specifications;
- acceptable substitutions;
- supplier links, stock and current pricing;
- minimum order quantities;
- consumables and spares; and
- the PCB revision to which the BOM applies.

Avoid making a single supplier's stock code the only component identifier.

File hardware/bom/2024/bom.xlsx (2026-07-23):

# | Date | Item | Description | Qty (tot) | Qty (order) | Price (Each) | Price (Total) | Proposed by | Link | Approved by (committee member) | Ordering Info
1 | 29/10/2024 | ESP32 C3 super mini | MCU used for the Project X, buying 40 extra in case it broke | 100 | 20 x 5pcs/order | 1.258 | 125.8 |  | https://a.aliexpress.com/_EGGhkAV
2 | 29/10/2025 | Pulseoximetry sensor (MAX30102) | Sensor used for the Project X, buying 20 extra in case it broke | 100 | 100 x 1pcs/order | 0.88 | 88 |  | https://a.aliexpress.com/_EIkHf9r
3 | 29/10/2026 | Battery holder | Big and Ugly, 2 needed for each board, buying 20 extra | 140 | 14 x 10pcs/order | 0.051 | 7.14 |  | https://www.aliexpress.com/item/1005007494224718.html
4 | 29/10/2027 | Coin cell battery | 3 V, 2 needed for each board, buying ~40 extra | 156 | 13 x 12pcs/order | 0.404 | 63.024 |  | https://www.batterystation.co.uk/energizer-cr2032-coin-cell-3v-lithium-batteries-12-pack/
5 | 29/10/2028 | Switch | SMT side mount, for turning on/off the battery | 80 | 8 x 10pcs/order | 0.058 | 4.64 |  | https://www.aliexpress.us/item/1005005881790558.html
 | 2024-11-25 | 220R resistor | For Project X, updated 25/11 | 400 |  | N/A | 2.5 |  | TE Connectivity 220Ω, 0805 (2012M) Thick Film SMD Resistor ±5% 0.33W - CRGH0805J220R | RS (https://uk.rs-online.com/web/p/surface-mount-resistors/8075743)
 | 2024-11-25 | yellow LED | For Project X, updated 25/11 | 400 |  | N/A | 16 |  | Lite-On2.6 V Yellow LED 2012 (0805) SMD, CHIP LED 0805 LTST-C170YKT | RS (https://uk.rs-online.com/web/p/leds/6920925P)
 |  |  |  |  |  |  | subtotal | 307.104
 |  |  |  |  |  |  | 0
 |  |  |  |  |  |  | 0
 |  |  |  |  |  |  | 0
 |  |  |  |  |  |  | 0
 |  |  |  |  |  |  | 0

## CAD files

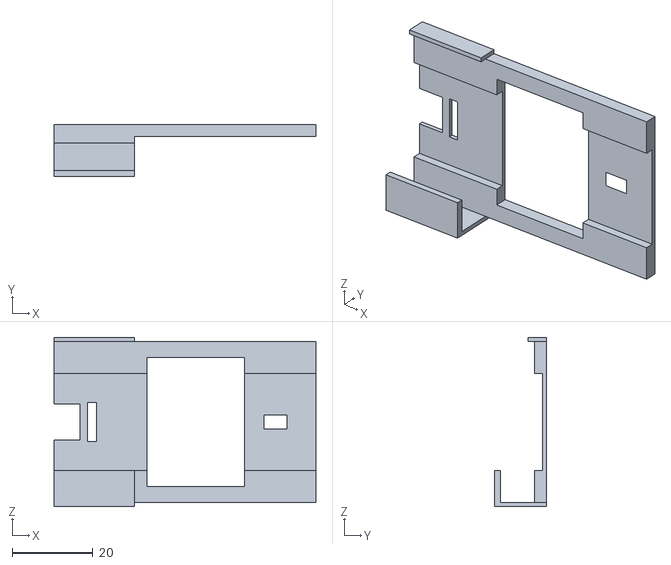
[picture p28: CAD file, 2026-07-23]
hardware/enclosure/2024/earlier-revisions/enclosure_v1.STL
65.0 x 13.0 x 42.0

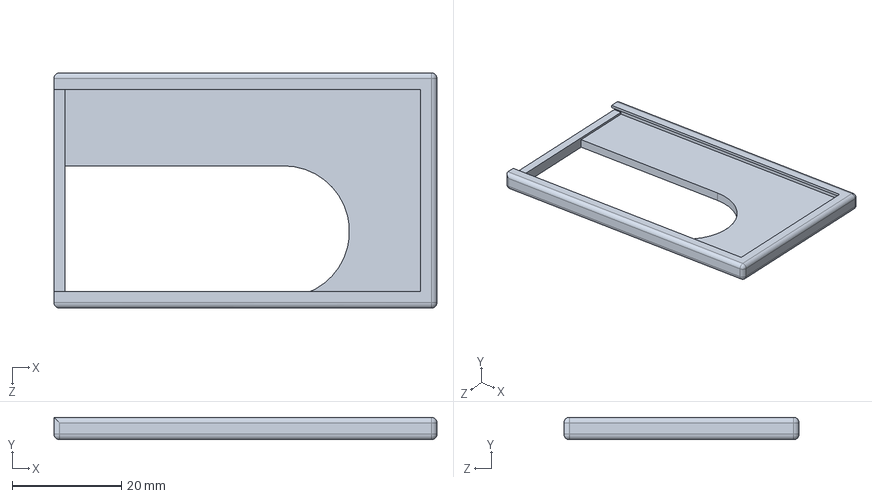
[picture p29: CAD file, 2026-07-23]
hardware/enclosure/2024/v3/enclosure_v3.1_shrink_back.SLDPRT
70.0 x 4.10 x 43.0 mm

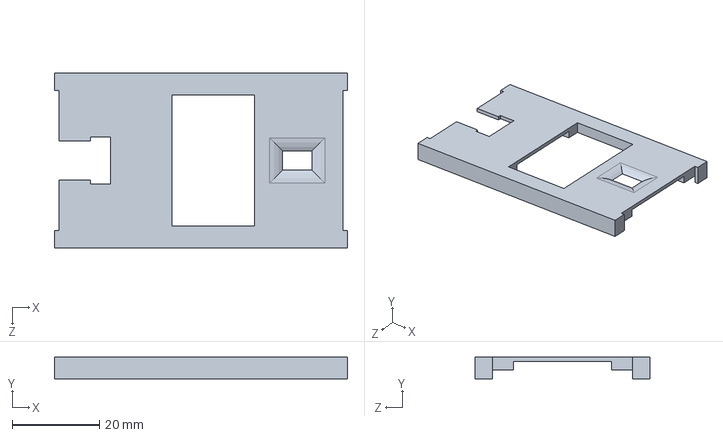
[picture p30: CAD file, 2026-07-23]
hardware/enclosure/2024/v3/enclosure_v3.SLDPRT
67.0 x 5.00 x 40.0 mm

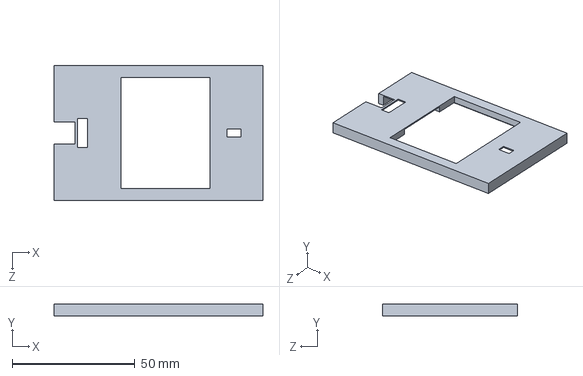
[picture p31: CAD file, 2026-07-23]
hardware/enclosure/2024/earlier-revisions/enclosure_for_v2.SLDPRT
85.0 x 5.00 x 55.0 mm

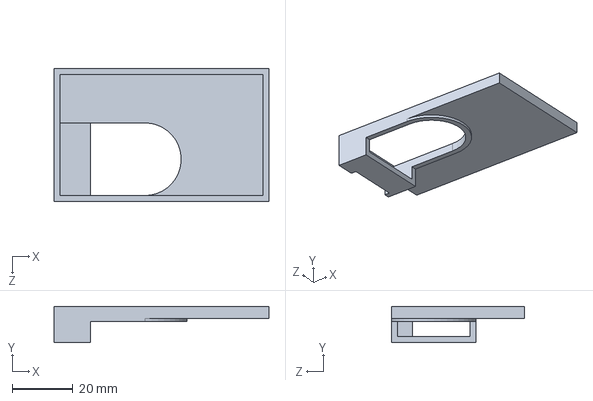
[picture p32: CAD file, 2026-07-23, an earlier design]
hardware/enclosure/2024/v3/enclosure_v3_back.SLDPRT
71.0 x 12.0 x 44.0 mm

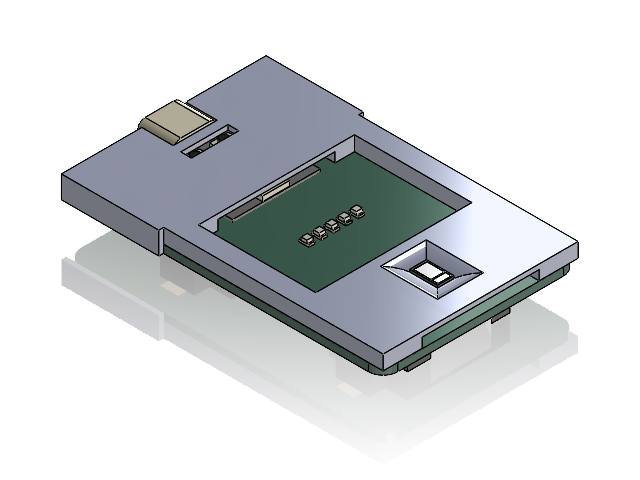
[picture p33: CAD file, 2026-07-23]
hardware/enclosure/2024/earlier-revisions/assem.SLDASM
LED_0805_2012Metric-0.step x 5
MH_ET_LIVE_BOARD v8.step
ESP32C3-SuperMini-1.step
Keystone_1060_1x2032.step x 2
session_1_pcb_PCB.step
enclosure

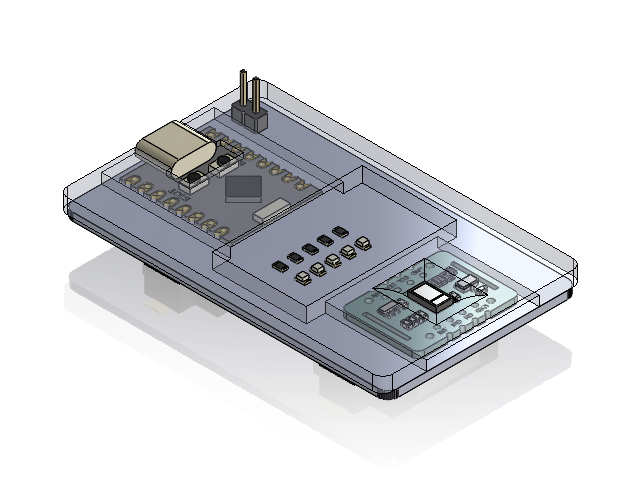
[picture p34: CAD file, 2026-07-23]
hardware/enclosure/2024/v3/Assem_v3.1.SLDASM
LED_0805_2012Metric-0_2.step x 5
R_0805_2012Metric-1_2.step x 5
MH_ET_LIVE_BOARD v8_2.step
ESP32C3-SuperMini-2_2.step
PinHeader_1x02_P254mm_Vertical_2.step
SW_DIP_SPSTx03_Slide_67x918mm_W673mm_P254mm_LowProfile_JPin_2.step
Keystone_1060_1x2032_2.step x 2
project_x_pcb PCB_2.step
enclosure_v3

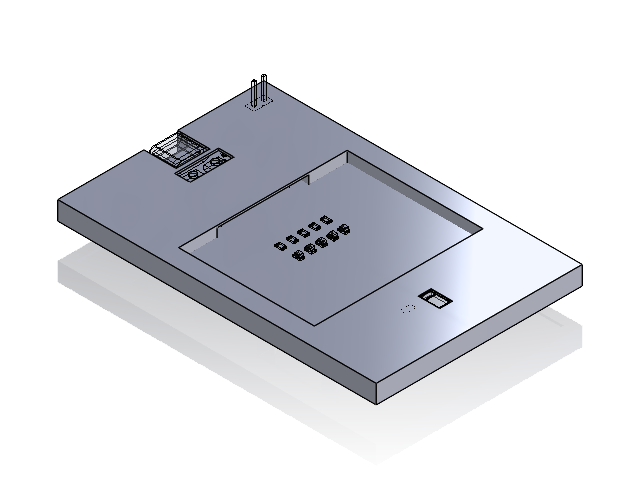
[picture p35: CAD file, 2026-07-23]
hardware/enclosure/2024/earlier-revisions/Assem_v2.SLDASM
LED_0805_2012Metric-0.step x 5
MH_ET_LIVE_BOARD v8.step
R_0805_2012Metric-1.step x 5
PinHeader_1x02_P254mm_Vertical.step
ESP32C3-SuperMini-2.step
Keystone_1060_1x2032.step x 2
SW_DIP_SPSTx03_Slide_67x918mm_W673mm_P254mm_LowProfile_JPin.step
session_1_pcb PCB.step
enclosure_for_v2

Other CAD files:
hardware/enclosure/2024/earlier-revisions/enclosure.SLDPRT
hardware/enclosure/2024/v3/enclosure_v3.1_back.SLDPRT
hardware/enclosure/2024/earlier-revisions/enclosure_for_v2.STL
hardware/enclosure/2024/v3/enclosure_v3.1_back.STL
hardware/enclosure/2024/v3/enclosure_v3.1_shrink_back.STL
hardware/enclosure/2024/v3/enclosure_v3.STL
hardware/enclosure/2024/v3/enclosure_v3_back.STL

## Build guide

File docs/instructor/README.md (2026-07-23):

# Instructor materials

## Recovered Project X 2024 files

- [Session 2 agenda](2024/session-02-agenda.txt)
- [Session 5 plan](2024/session-05-plan.docx)
- [Session 2 I2C code examples](../../firmware/examples/session-02/)

These are historical working documents, not approved current delivery plans.
Review timings, terminology, dependencies, safeguarding and safety controls
before reuse.

Before delivering this project, add or confirm:

- session plan, timings and learning outcomes;
- required equipment and a complete bill of materials;
- tested Arduino, ESP32 core and library versions;
- setup and troubleshooting instructions;
- current risk assessment and venue controls;
- accessibility adaptations;
- expected learner starting point; and
- reset and pack-down procedures.

Do not place attendance, consent, health or contact information here. Those
records must remain outside the public repository in approved secure storage.

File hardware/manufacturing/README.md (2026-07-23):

# Manufacturing outputs

This directory is for generated, reviewed fabrication outputs. Editable source
belongs in `../kicad/`.

The `gerbers/` files were inherited from the 2024 project and are not currently
approved for a new production run. Once validated, publish a dated/versioned
bundle through a GitHub Release and record:

- source commit;
- KiCad version;
- board revision;
- ERC and DRC result;
- fabricator-specific settings, if any; and
- reviewer and approval date.

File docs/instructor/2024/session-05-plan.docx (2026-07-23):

# Project X Term 1 Session 5 Plan

# Objectives of this session

Primary Objectives:

- Distribute bespoke/generic PCB mood cards to students
- Program Arduino to understand i2c
- Program PCB mood cards

Secondary Objectives:

- Understand the high-level principle of I2C (link to Term 1 Session 2)
- Understand PCB manufacturing process (link to Term 1 Sessions 3 and 4)

# Timings

1700 – 1715: Introduction videos

YouTube video

Martin PCB video

Grace video

1715 – 1720: I2C briefing

1720 – 1800: I2C exercise

1800 – 1805: Code debugging brief

1805 – 1835: Code debugging exercise

1835 – 1840: Move

Please add more specific details about timing and content for the following:

1700-1715 Video introduction

- Include video about PCB fabrication (link to sessions 3 and session 4 PCB design)
- Video of Mood card
- Include simple I2C communication between ESP8266 and Arduino from session 2 (link to session 2 I2C communication)

1715 – 1720

-I2C briefing

1720– 1810: I2C Arduino exercise (from scratch)

- Recap the I2C material in session 2, tell pupils what they need to do for the exercise
- Give pupils incomplete code (e.g undefined IO pins etc) ask them to complete it make it work.
- Volunteers checking for right answers, and pupils got the right answers could start the PCB mood board programming challenge.

1805 – 1810: Code debugging brief

1810– 1835: PCB mood card programming Challenge

- Presenters overview of the programming exercise to explain what the pupils need to do.
- Introduce the rules of the challenge that the first 10 people completed will get the PCB mood card as the reward.
- Volunteers ask them to complete it to make it work. Volunteers walk around to check the answer and announce the winners.
- If time allowed give and explain the right answer.
- Hands out the awarded PCB board.

1835 – 1840: Move kids from project lab to 7th computer room

1840 –1845: Group picture

1845 – 1855: End

- Debrief by most likely Thomas
- Send pupils out of the building.

# Tools / Equipment / Resources

For the introduction

- PCB fabrication video
- I2C briefing slides
- 90 Jumper wire m-m
- 60 x Arduino + cable

For the PCB mood card programming exercise

- Generic PCBs x 10
- Incomplete code

Logistical Considerations

- How will the generic and bespoke PCB mood cards be distributed to the pupils?
- Pupils will be split between the PROJECT LAB and 7^t^h floor computer room
- Need to know how many pupils can be accommodated in the project lab and the 7th floor computer room
- Some computers don’t have functional Arduino IDE in the project lab – what can we do about that?
- 7^t^h floor computer room may not have ESP8266 driver – need to find out??
- If 7th floor computers can’t program ESP8266, only Arduinos can be used there and ESP8266 used in the project lab
- If ESP8266-Arduino I2C communication practical is done, there needs to be enough of each MCU

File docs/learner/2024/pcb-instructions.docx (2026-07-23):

PCB Instruction for Project X

Junzhe Chen, Oli Sharratt, Yuxuan Han

General workflow:

When designing a PCB, the first step would be drawing out a schematic. A schematic is a circuit diagram that shows the electronics components and its connections by its symbol. An example of a schematic looks like the following:


After the schematics, the footprint of components (e.g. resistors, LEDs, battery holders etc). Footprint is the physical contacts between the component and the PCB.

Schematics tells the circuit diagram and connection of the circuit; footprint states the physical component to PCB contacts. After drawing out the schematics and assigning footprints to associated symbols, the next step is to draw the physical board, which brings to the PCB layout

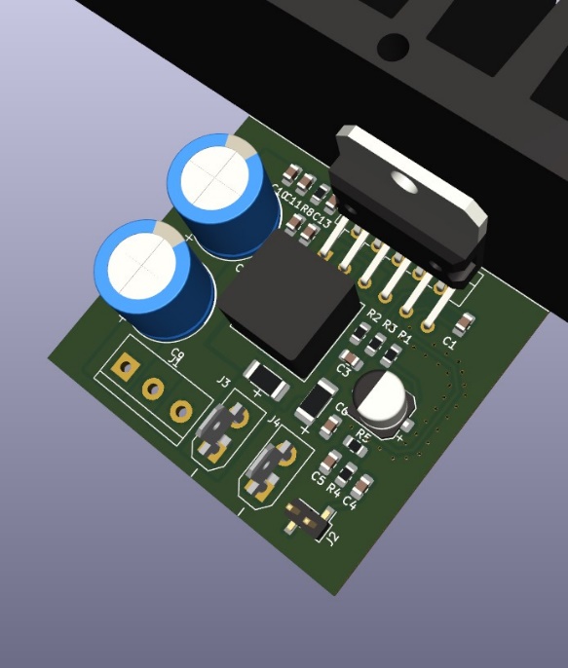
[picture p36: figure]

The left figure above shows a PCB design file, the right figure shows the 3D rendered image of the PCB design. The PCB design file contains the footprints of schematic symbols and traces that connects them together. In default KiCAD two-layer design, the top layer is coloured in red, and the bottom layer is coloured in blue. Notice that there is large amount of area covered by copper, that connects the ground or GND of the circuit, which is a commonly used method to minimise the return path impedance.

After finish designing the PCB, it will be sent over to the UCL PCB lab to produce. Usually, it takes one day to produce a double layer PCB. After the PCB is fabricated, the components will be populated and soldered onto the PCB. Then, the test for the PCB can begin.

To begin with:

To begin with, we have drawn part of the important bit of the mood card project: the microcontroller and the sensor. These are placed in the schematics and the layout. Your tasks will be the followings:

- Connect the traces between the microcontroller and the sensor
- Design and layout your own LED circuits
- [advanced] Try to make the footprints of the microcontroller and sensor

Start with KiCAD:

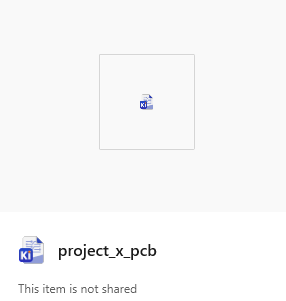
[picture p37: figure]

Firstly, open the KiCAD project file with the icon shown in the right. The KiCAD project file contains both the schematic, and the PCB layout files inside the file directory and it will be displayed in the Project Files section shown in the screenshot below:

Schematics and PCB file:

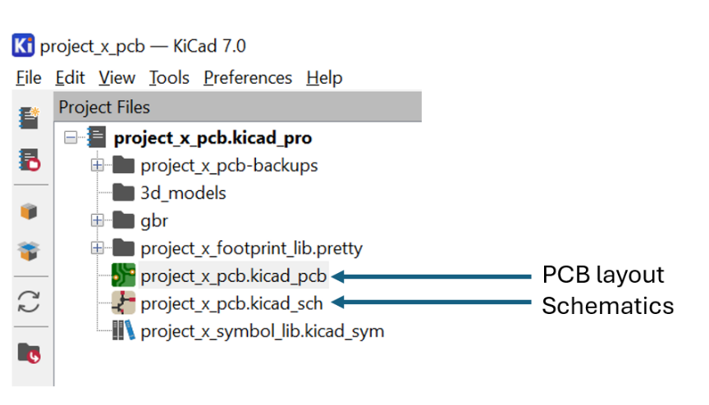
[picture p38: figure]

The screenshot on the right displays what will be seen when opening the project file. The most important files are the schematics and the PCB layout, which ends with _sch and _pcb respectively. Try to open the schematics and PCB files by double clicking it, you should be able to see the followings shown below:

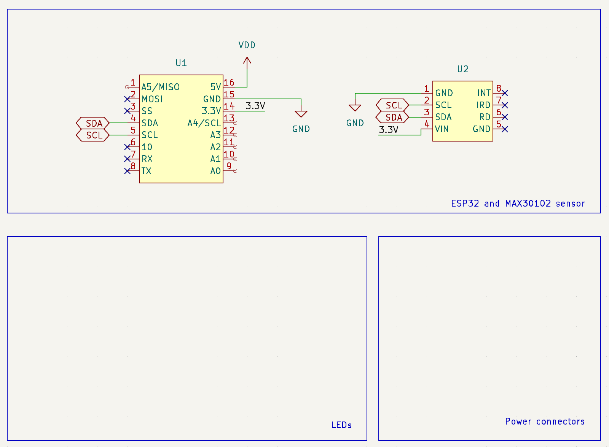
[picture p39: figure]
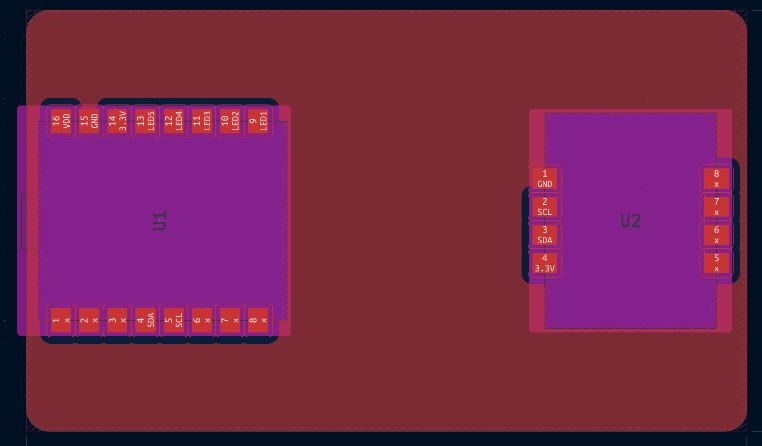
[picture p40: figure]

The left figure shows the schematic template, and the right figure shows the PCB in the design template. The microcontroller (U1) and the sensor (U2) has been placed. However, the traces have not been placed yet.


You will need to route the traces between the microcontroller and the sensor, design your LED circuits in schematics and lay it out onto the PCB, as well as adding a battery connector to the PCB to supply power to the microcontroller and the sensor

Start with schematics:

Let’s start the design from schematic, On the right-hand side of the schematic editor, there is a tool bar. You will use the toolbar to edit, add the components and wiring the connections most of the time. The commonly used tools with its shortcut keys are labelled in the diagram on the right:

Add components:


To add a component, click the add components icon or press <A> in the keyboard. The following window on the right will be opened. The components can be found by using the search bar on the top. In this example, we are searching a LED in the symbol library and the LED symbol is shown on the top right. After selecting the symbol you want, press OK and then the symbol can be placed on the schematic.

Task: Please try to place one LED and one resistor in the schematic’s LED region

Connecting the wires:

After placing down the components, we can start connecting them. To connect components together, we can move the cursor close to the unconnected pin (marked with small circle), and a wire will be generated for us to connect. A better method is to use the Add a wire in the toolbar (or press <W> for the shortcut), the connect the symbol with wires.

You may notice that the value of resistor is R but not the exact value we want (220). To change this, double click on the R, then the value of the resistor can be modified in the following window:

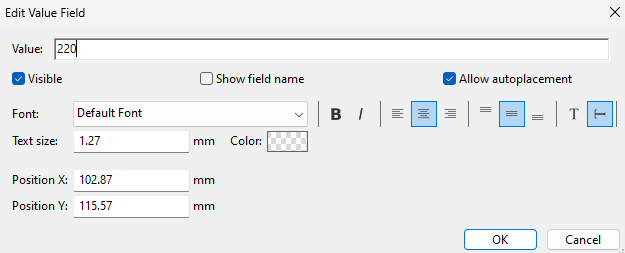
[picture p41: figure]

After that, the value of the resistor can be changed.

Connecting with nets:

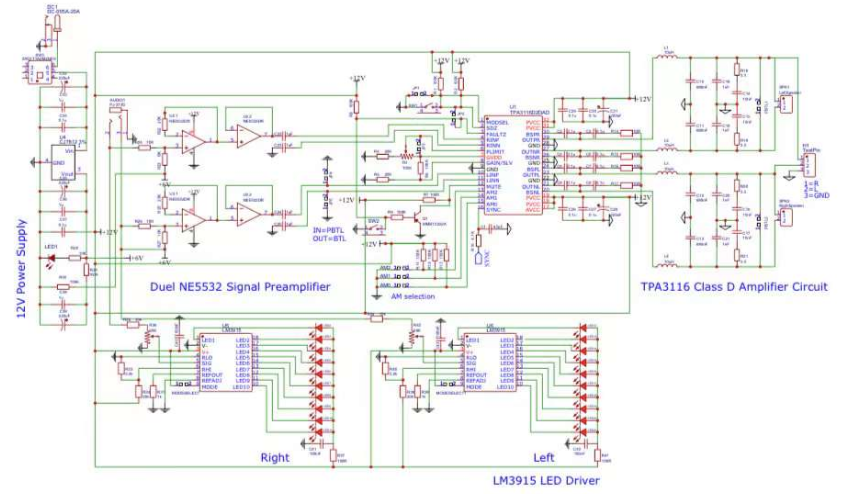
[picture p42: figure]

When there are more and more wires present in the schematic, the schematic can be difficult to read. A very bad example is my first ever PCB, which only used the wire connections, and no net connection has been implemented.

Using net connection can greatly simplify the mess of wires connection. Also, the net will have its name in the PCB layout stage, which can sometimes save time during the Design Rule Check, where you know which net connection is wrong.

There are mainly two types of nets, The first type is called as Net Label (shortcut: <L>), as the name suggests, it “labels” a certain net and give it a name. If there are two nets that has the same label, they will be connected together. This can be verified by using the highlight tool

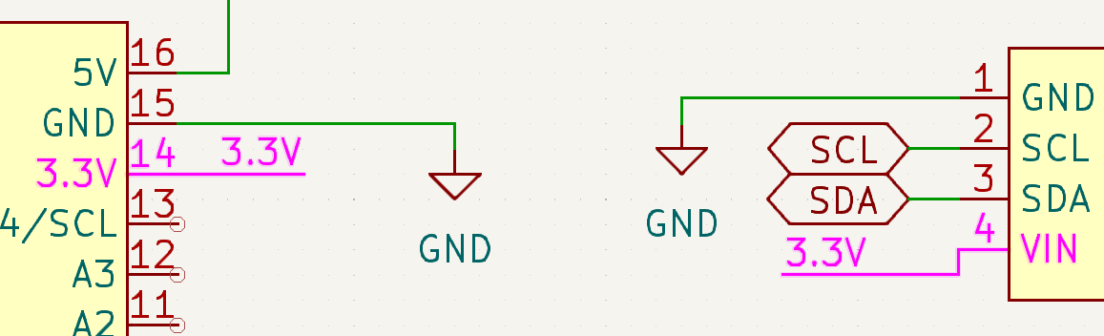
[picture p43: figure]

Net label is a very good tool to give certain net a name. However, it doesn’t tell the nets’ characteristics, such as whether it is the input or the output. Also, net label only works on a single sheet. If the design has multiple sheets, the label will not be inherent to the subsequent sheets.

Another type of label in KiCAD is the global label (shortcut: <Ctrl-L>). Global label not only connects the net with same label together, but it also indicates the net’s characteristics. We can configure the label to be the input, the output and more. As the name suggests, global label can be inherent through different schematic sheets.

Task: Please try to connect the LEDs to the microcontroller using global labels.

Assign footprints:

By now we should be able to finish the schematic design, which means the component symbols have been correctly connected using net labels and checked by the volunteers. After that, it is the time to assign the symbols with the corresponding footprints.

To assign the footprints, use the top menu bar and click Tools/Assign Footprints…, or click the follow icon on the top bar

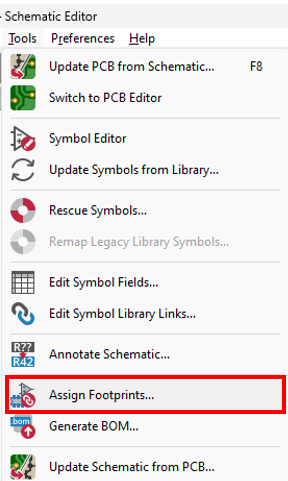
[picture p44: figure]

After opening the footprint assignment tool, it will show the following:


The footprint assignment tool is split into three columns. The left column is the footprint library, the middle one is the symbol in our schematic, the symbols without footprint assigned are highlighted in yellow. The right column shows the filtered footprints. The footprint filter is on the top right side with a search bar.

To find the footprint using the footprint filter, type the name of the footprint in the search bar, and the filtered footprint should be available in the right column, as shown in the figure below.

When correct footprints are found, double click on the correct footprint and then the footprint will be assigned to the symbol.

The footprints that will be used for Project X are listed below:

Component | Footprint name | Searc
Resistors | R_0805_Handsolder
LEDs | LED_0805_Handsolder
Batteries | PinHeader_1x02 P2.54mm_Vertical

Task: Assign the footprints to the symbol. After that, ask one volunteer to check

Progress check: please ask one of the volunteers to check if your schematics is correct. If so, you could move onto the PCB design.

PCB design, a new start

Congratulations to finish your schematic design and get it checked by the volunteers! Now you can move onto the PCB design part.

To start the PCB design, first open the _pcb file and then press the Tools/Update the PCB from schematics on the manu bar, or press <F8> on the keyboard.

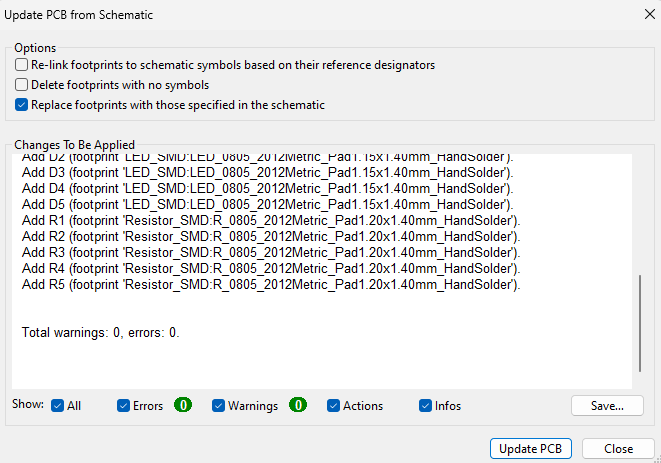
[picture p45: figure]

The following window will pop up and if there is no error or warnings, click Update PCB to sync the schematics and the PCB. You should see the added component footprints appears on your mouse cursor shown in the figure below:

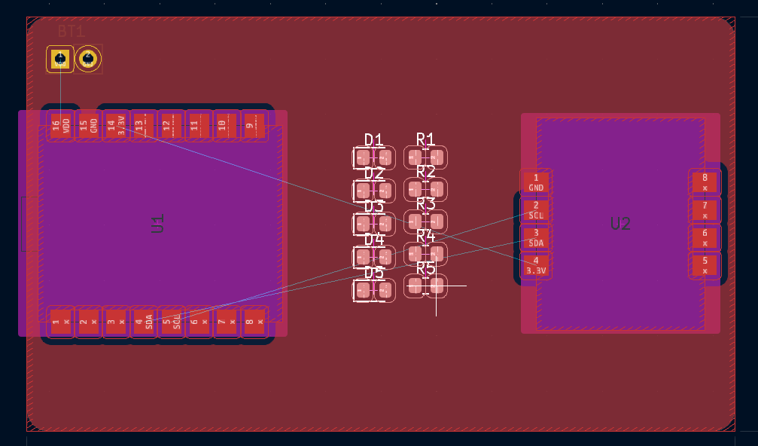
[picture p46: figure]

You may notice that there are thin lines connecting from one place to another in the PCB layout, these are ratlines and that indicates the physical connection between different pins.

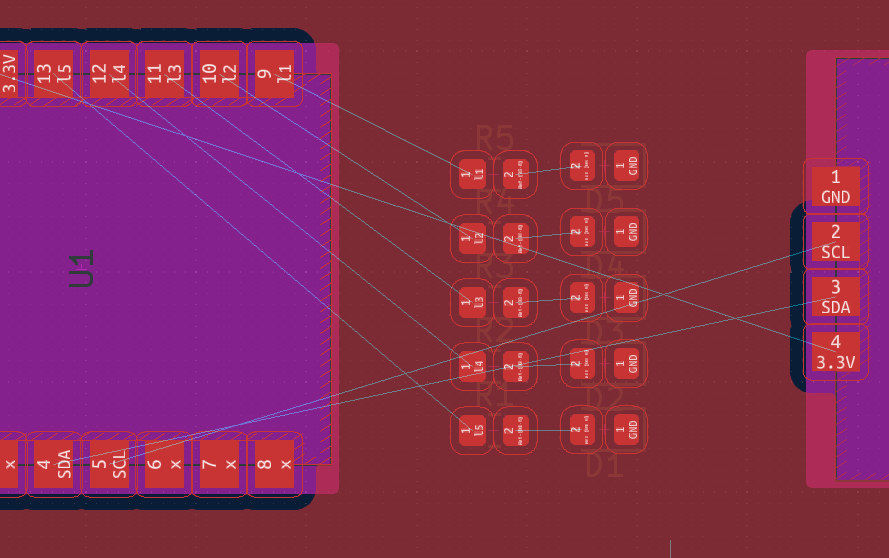
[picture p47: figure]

When choosing where to place the components, it is best to look at the ratlines so that the ratline has the least crossing. As ratline indicates the physical connections between the pins, making them to have least crossing will make the trace routing much easier.

Setting up the properties:

After placing the components to the appropriate position, the routing can begin. But before start routing, it is important to set appropriate trace width, clearance and other parameters so that the board can be manufactured from the UCL lab. To do that, click board setup, which is on the top right corner of the PCB editor (screenshot below)

After opening the board setup, go to the constraints page and fill in the following parameters. The Copper section is the most important section for reaching the UCL lab manufacture. Follow the constraints shown above so that the constraints requirements can be met for PCB manufacture.

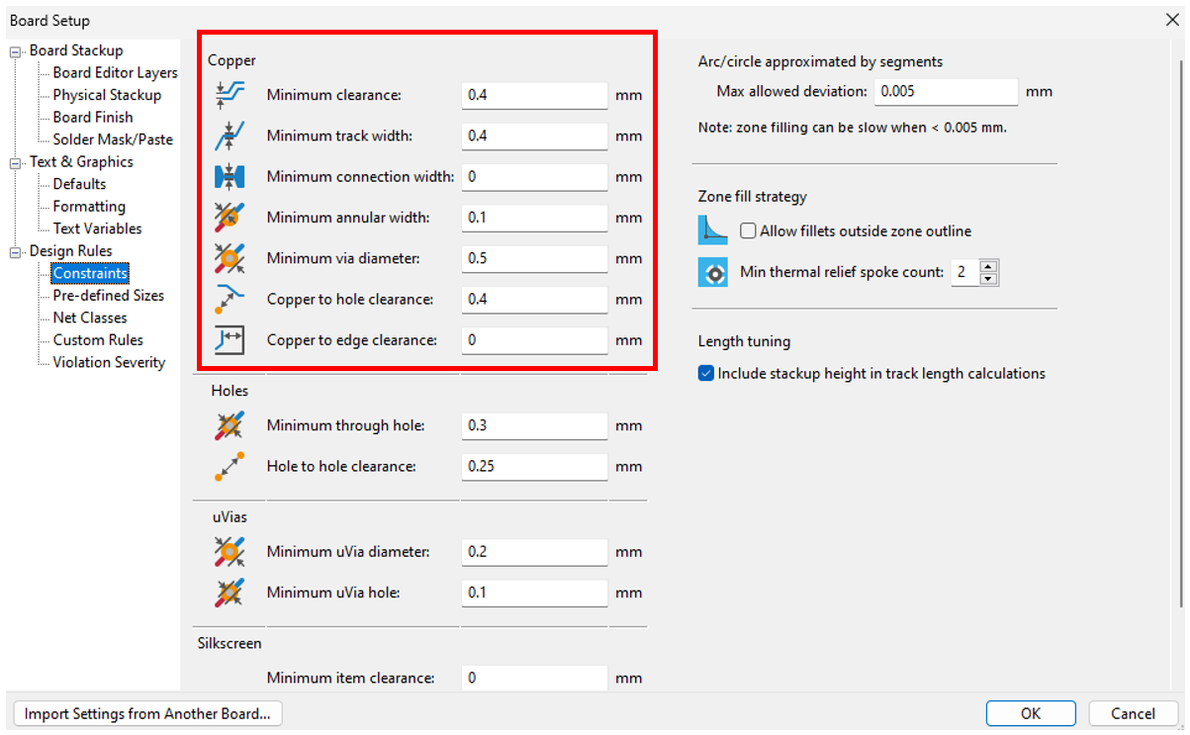
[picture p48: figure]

The trace width should also be set for the routing. Go to Pre-defined Sizes (which is just under Constraints, and the Track property should be shown on the left column (see screenshot below). As indicated by the constraints, the track cannot be thinner than 0.4 mm. So, the track width that is larger than 0.4 mm should be added. The track for power node (e.g. VDD, 3.3V) should be set thicker to reduce the track resistance, multiple track width can be set in this case.

For vias (in the next column), UCL uses specific size vias. The via size should be set as same as the given example (Diameter = 1.2 mm, Hole = 0.5 mm).

Task: Set the constraints and pre-defined sizes and ask one of the volunteers to check

Track routing:

After setting the board setup, it is the time to route the tracks. To route the track in KiCAD, first place the cursor on the pad we want to route, then press the routing key <X> to enter the routing mode. The pads that need to be connected will be highlighted under correct routing setting (shown in the following screenshot)

A copper pour is added for this board, which connects all the ground connection. The When routing tracks, the track goes over the copper pour, thus the reason why you may see two red layers. To resolve that problem, press <B> to rebuild the copper pour, then the copper pour will be updated to leave the space for the track to go through.

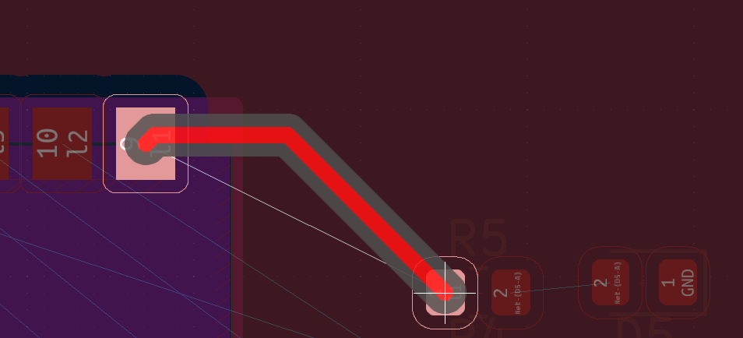
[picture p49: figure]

When finished routing, left click to finish the track. Then, press <B> to rebuild the copper pour.

Using vias to switch layer:

Sometimes, it is difficult to route certain tracks that goes across other tracks. In this case, it is good to switch the layer to “bridge” the track over (or under) it.

To connect the top and bottom together, a via is required. Via is a hole that is made right between the bridging tracks, and it connects the top and bottom together by plating the copper across the hole. When placing the track to the desired position, press <V>, then a via will be generated on the cursor. Move the via to the desired place, then click the left mouse button, the via will then be placed.

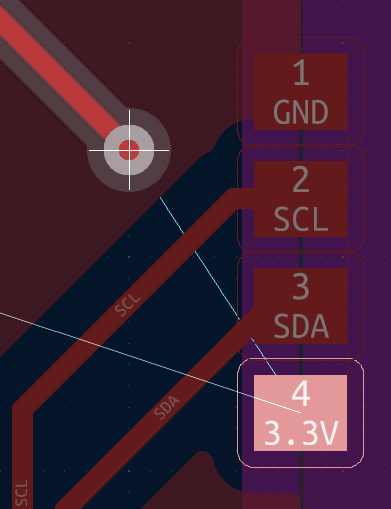
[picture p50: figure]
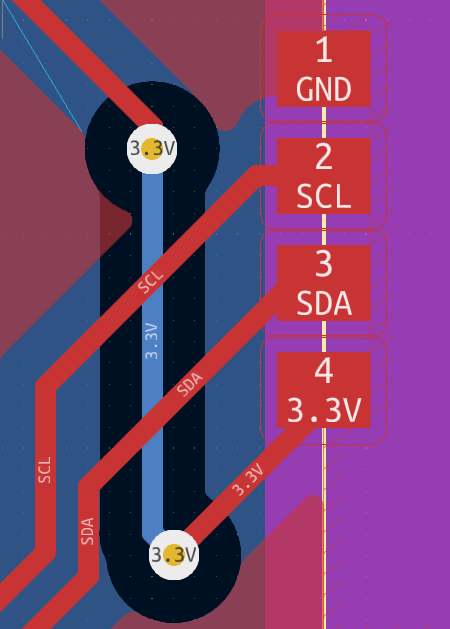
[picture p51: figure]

After placing the via, the KiCAD will automatically switch the track to the bottom layer, where the background is showing in blue. Then route the bottom track across the “bridge”, press <V> again, then the track will be completed as shown in the right screenshot above.

Design Rule Check:

After the routing has been completed, it is good practice to check the design rule before sending the design file to be manufactured. The design rule check (DRC) can be found in Inspect/Design Rule Checker in the menu bar shown in the screenshot below:

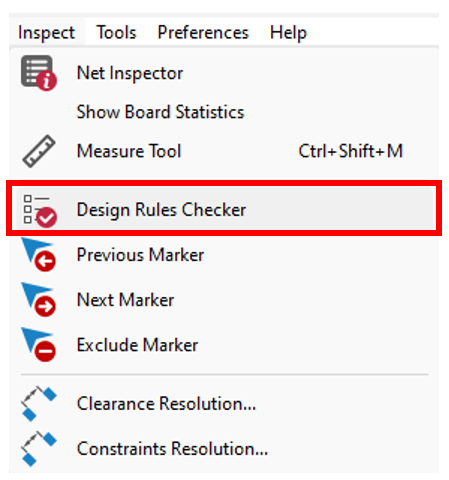
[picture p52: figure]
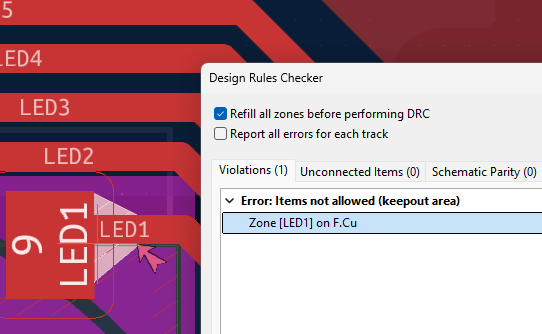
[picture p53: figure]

If the DRC reports an error, a quick way to locate the error is by double-click the error. Usually, the error will be highlighted as shown above in the right screenshot. It is important to keep the design error-free, so that it maximizes the chance of getting a working board after the board have been fabricated out. The warning can sometimes be ignored.

Progress check: Congratulations to make it till this far! The PCB should be ready and please ask one of the volunteers to check if your board is correct and ready for fabrication!

Misc:

ESP32 C3 super mini related

Docs can be found here (https://www.sudo.is/docs/esphome/boards/esp32c3supermini/)

MAX30102 related

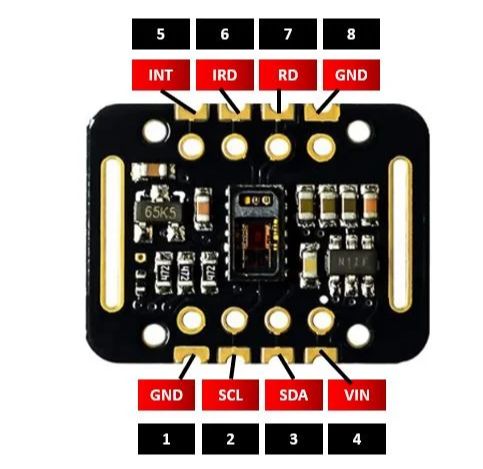
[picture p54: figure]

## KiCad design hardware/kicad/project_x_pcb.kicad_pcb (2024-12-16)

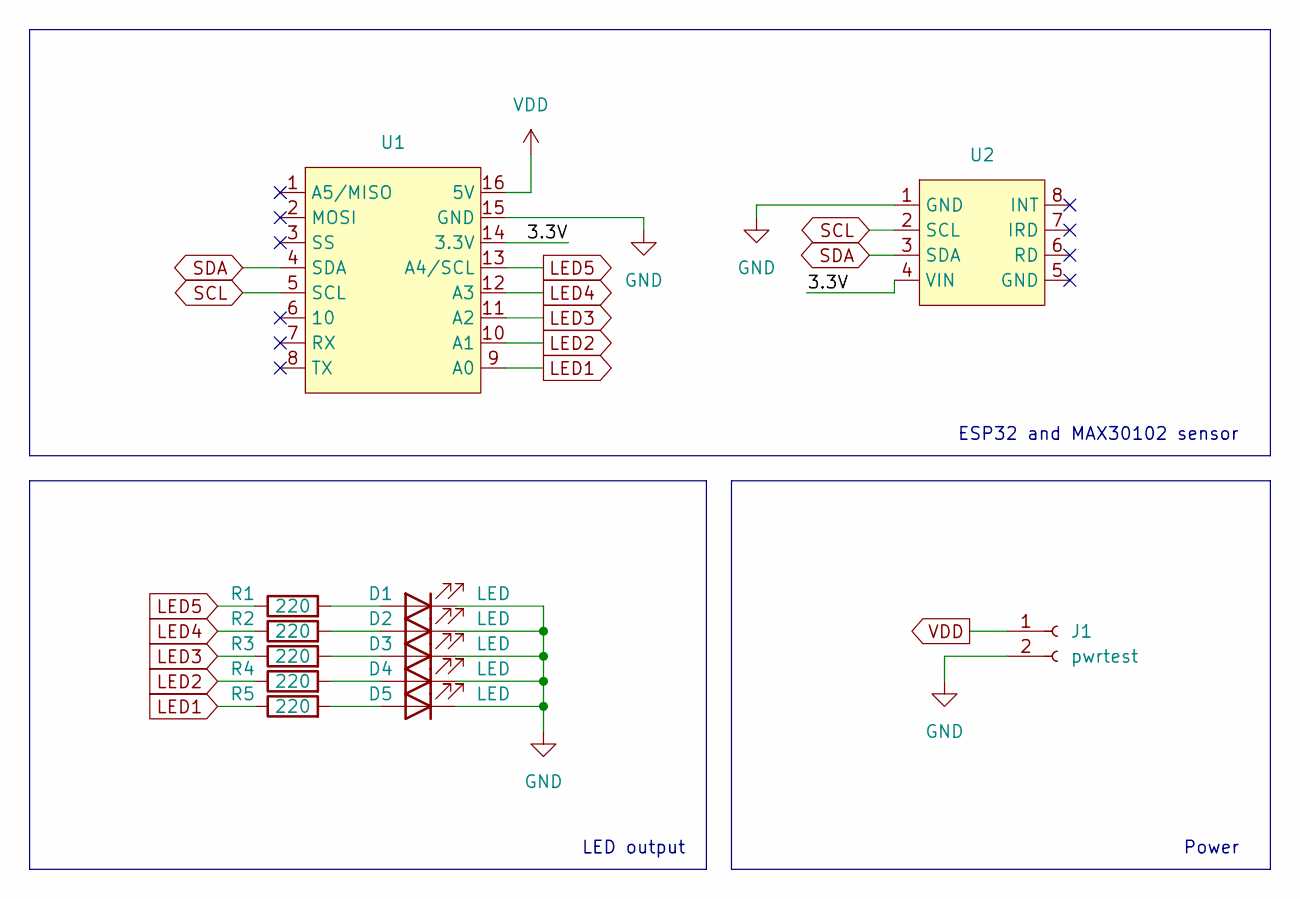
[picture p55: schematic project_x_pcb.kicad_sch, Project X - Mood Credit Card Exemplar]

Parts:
D1, D2, D3, D4, D5: LED; LED_0805_2012Metric_Pad1.15x1.40mm_HandSolder
J1: pwrtest; PinHeader_1x02_P2.54mm_Vertical
R1, R2, R3, R4, R5: 220; R_0805_2012Metric_Pad1.20x1.40mm_HandSolder
U1: esp32_super_mini
U2: MAX30102

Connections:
/3.3V: U1.14 (3.3V), U2.4 (VIN)
GND: D1.1 (K), D2.1 (K), D3.1 (K), D4.1 (K), D5.1 (K), J1.2, U1.15 (GND), U2.1 (GND)
LED1: R5.1, U1.9 (A0)
LED2: R4.1, U1.10 (A1)
LED3: R3.1, U1.11 (A2)
LED4: R2.1, U1.12 (A3)
LED5: R1.1, U1.13 (A4/SCL)
unnamed: D1.2 (A), R1.2
unnamed: D2.2 (A), R2.2
unnamed: D3.2 (A), R3.2
unnamed: D4.2 (A), R4.2
unnamed: D5.2 (A), R5.2
SCL: U1.5 (SCL), U2.2 (SCL)
SDA: U1.4 (SDA), U2.3 (SDA)
VDD: J1.1, U1.16 (5V)

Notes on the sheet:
Power
ESP32 and MAX30102 sensor
LED output

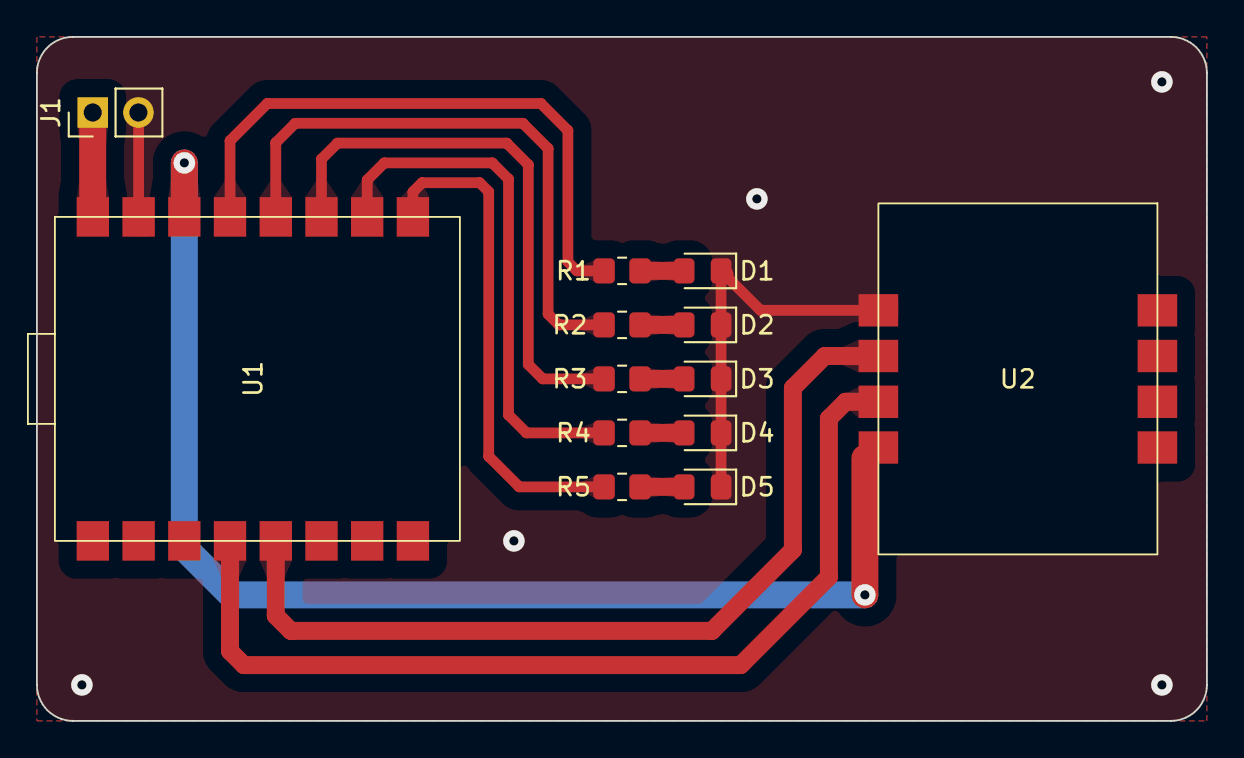
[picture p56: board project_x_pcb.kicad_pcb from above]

Board: 2 copper layers, 65.0 x 38.0 mm, 13 parts (0 on the bottom side), 15 nets.

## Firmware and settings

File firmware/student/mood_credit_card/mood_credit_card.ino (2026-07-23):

// SPDX-License-Identifier: MIT
// Copyright (c) 2024 Junzhe Chen and Mood Credit Card contributors

//------------------------------------------------------------------------------------------------//
// Here are the codes for the Project X. the heartrate readout function has been packaged
// into a function, called "readBPM()". This function returns a valid value if the sensor
// have detected the heartrate. it returns -1 if a faulty signal has appeared

// You might need to install the MAX3010x Sensor Library on the lab computer to make sure 
// everything is functioning well. To install the library, go to Tools/Manage Libraries
// and search for "MAX3010x Sensor Library", then install it. If the program passes the 
// compile, that means the library have been installed and you are good to go.

// Please write your codes in the ----- void main() { <HERE> } -----, there are few lines 
// of instructions that may or may not help with your coding process in the main loop.

// Good luck, and have fun coding!
// Junzhe Chen, 09/12/2024

//----------------------------------CONFIGURATION, DO NOT CHANGE----------------------------------//
#include <MAX3010x.h>
#include "filters.h"

// Sensor (adjust to your sensor type)
MAX30105 sensor;
const auto kSamplingRate = sensor.SAMPLING_RATE_3200SPS;
const float kSamplingFrequency = 400.0;

// Finger Detection Threshold and Cooldown
const unsigned long kFingerThreshold = 10000;
const unsigned int kFingerCooldownMs = 500;

// Edge Detection Threshold (decrease for MAX30100)
const float kEdgeThreshold = -2000.0;

// Filters
const float kLowPassCutoff = 5.0;
const float kHighPassCutoff = 0.5;

// Timestamp of the last heartbeat
long last_heartbeat = 0;

// Timestamp for finger detection
long finger_timestamp = 0;
bool finger_detected = false;

// Last diff to detect zero crossing
float last_diff = NAN;
bool crossed = false;
long crossed_time = 0;

// Timer
long currentMillis, prevMillis = 0;

// Filter Instances
HighPassFilter high_pass_filter(kHighPassCutoff, kSamplingFrequency);
LowPassFilter low_pass_filter(kLowPassCutoff, kSamplingFrequency);
Differentiator differentiator(kSamplingFrequency);

//------------------------------------------------------------------------------------------------//
//----- Define your variables here -----//
int bpm_out = 0;


//----- Defined variables ends here -----//

//----- Setup Function (runs once) -----//
void setup() {
  Serial.begin(115200);  //baud rate

  //Sensor initialisation
  if (sensor.begin() && sensor.setSamplingRate(kSamplingRate)) {
    Serial.println("Sensor initialized");
  } else {
    Serial.println("Sensor not found");
    while (1)
      ;
  }
}

//------------------------------------------------------------------------------------------------//
//----- Main Function (repeats forever), write your codes below -----//
void loop() {
  currentMillis = millis();
  if (currentMillis - prevMillis > 1000) {
    // Function inside this loop get called once per 1000 ms
    // You can put your BPM update, LED brightness update or anything else here





    prevMillis = currentMillis;
  }

  //----- Define your LEDs here -----//
  // analogWrite(<#LED>, <brightness>) can be used to give LED variable brightness
  // digitalWRite(#LED>, <HIGH/LOW>) will output either fully bright / fully dark

  // Try using if-else statement, analog/digitalWrite to control the LED
  // regarding to your detected heart rate!




  
}

//------------------------------------------------------------------------------------------------//
//----- pre-defined function, DO NOT CHANGE -----//
int readBPM() {
  auto sample = sensor.readSample(1000);  // Read sensor data
  float current_value = sample.red;

  // Finger detection using raw sensor value
  if (current_value > kFingerThreshold) {
    if (millis() - finger_timestamp > kFingerCooldownMs) {
      finger_detected = true;
    }
  } else {
    // Reset filters and variables when the finger is removed
    differentiator.reset();
    low_pass_filter.reset();
    high_pass_filter.reset();
    finger_detected = false;
    finger_timestamp = millis();
    return -1;  // Return -1 if no finger is detected
  }

  if (finger_detected) {
    // Process signal with filters
    current_value = low_pass_filter.process(current_value);
    current_value = high_pass_filter.process(current_value);
    float current_diff = differentiator.process(current_value);

    if (!isnan(current_diff) && !isnan(last_diff)) {
      // Detect zero-crossing (heartbeat event)
      if (last_diff > 0 && current_diff < 0) {
        crossed = true;
        crossed_time = millis();
      }

      if (current_diff > 0) {
        crossed = false;
      }

      // Detect falling edge of the waveform
      if (crossed && current_diff < kEdgeThreshold) {
        if (last_heartbeat != 0 && crossed_time - last_heartbeat > 300) {
          // Calculate BPM
          int raw_bpm = 60000 / (crossed_time - last_heartbeat);
          bpm_out = raw_bpm;
        }

        // Reset for next detection
        crossed = false;
        last_heartbeat = crossed_time;
      }
    }

    last_diff = current_diff;
  }
  return bpm_out;
}

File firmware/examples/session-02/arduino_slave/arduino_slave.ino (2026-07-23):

// SPDX-License-Identifier: MIT
// Copyright (c) 2024 Mood Credit Card contributors

// Slave Code
// This code is to be uploaded onto the Arduino Uno
// The code receives any data (string) that was sent
// The code prints the string into the serial monitor

// Include the required Wire library for I2C
#include <Wire.h>

#define BUFFER_SIZE 32 // Maximum I2C buffer size

char receivedText[BUFFER_SIZE]; // Buffer to store received data
int textIndex = 0;

void setup() {
  // Start the I2C Bus as Slave on address 9
  Serial.begin(9600);
  Wire.begin(9);
  // Attach a function to trigger when something is received
  Wire.onReceive(receiveEvent);
}

void receiveEvent(int bytes) {
  // Reset the index to 0 to prepare for storing a new message
  textIndex = 0;

  // Continue reading data from the I2C buffer as long as there are bytes available
  while (Wire.available()) {
    char c = Wire.read(); // Read one character from the I2C buffer

    // Check if there is space in the buffer to store the character
    // Leave room for the null-terminator to mark the end of the string
    if (textIndex < BUFFER_SIZE - 1) {
      receivedText[textIndex++] = c; // Store the character and increment the index
    }
  }

  // Add a null-terminator at the end of the array to convert it into a proper C-string
  receivedText[textIndex] = '\0';
}

void loop() {
  // Check if a message has been received (textIndex > 0 means data is in the buffer)
  if (textIndex > 0) {
    // Print the received message to the Serial Monitor
    Serial.println("Received: " + String(receivedText));

    // Reset the index to 0 to indicate the message has been processed
    // and the buffer is ready for the next message
    textIndex = 0;
  }
}

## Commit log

2024-12-16 Update Project X Files
    Added session scripts and exemplar PCB files.
    [ESP32C3-SuperMini.stp, MAX30102_MH_ET_LIVE_BOARD_v8.step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]
2026-07-23 Organise Mood Credit Card teaching materials
    [Assem_v2.SLDASM, Assem_v3.1.SLDASM, ESP32C3-SuperMini.stp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]
